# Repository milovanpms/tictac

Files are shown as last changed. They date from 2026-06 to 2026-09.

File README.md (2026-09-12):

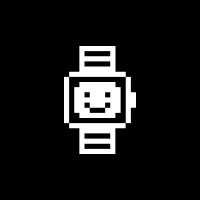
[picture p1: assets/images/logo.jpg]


**Tictac is a smartwatch prototype built on STM32G4, featuring heart rate monitoring, step counting and Bluetooth time sync on an e-ink display.**

Tictac is built around an e-ink display, a PPG heart rate sensor, a 6-axis accelerometer and a Bluetooth module, all packed into a custom-routed PCB and a fully 3D-printed enclosure. 

*The project spans embedded C on STM32G4, signal processing prototyped in MATLAB, PCB design in Altium Designer, mechanical design in Fusion 360, and a companion Android app; all developed from scratch over one semester.*

<p align="center">
  
  
  
  
  
  
</p>

<h1 align="center"></h1>

<h5 align="center"><a href="https://milovan.me">milovan.me</a></h5>

## In a nutshell
- **What** : A smartwatch prototype with heart rate monitoring, step counting, time display and Bluetooth sync.
- **Why** : We wanted a project that was both technically ambitious and tangible; something you can actually wear and demo.
- **Context** : Embedded systems student project, two-person team.

## Showcase

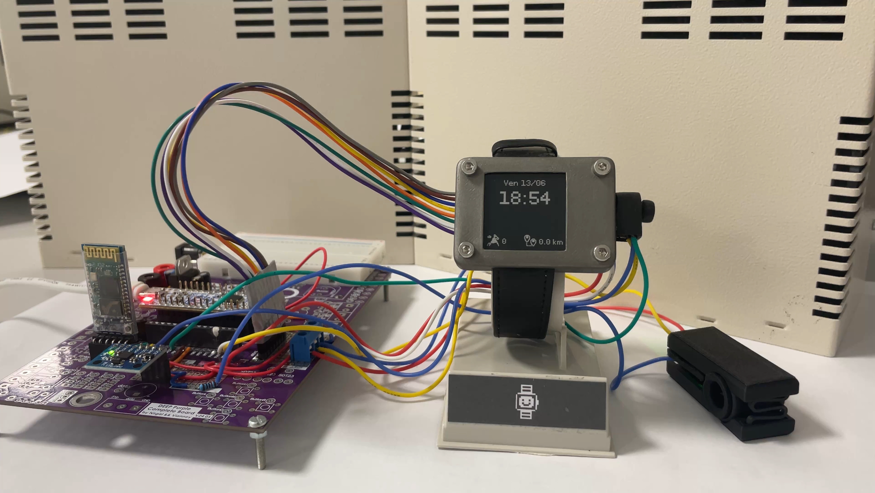
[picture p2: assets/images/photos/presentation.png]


## Documentation
### Find your happiness:
- ⚙️ [Hardware Architecture](./docs/architecture.md): Component list, pin mapping and wiring
- 🛠️ [Firmware](./docs/firmware.md): STM32G4, state machines, code architecture
- 📶 [Connectivity](./docs/connectivity.md): Bluetooth usage and handling
- 💓 [Heart-Rate Measurement](./docs/heartrate.md): PPG acquisition, bandpass filtering and BPM calculation
- 👟 [Step Counter](./docs/stepcounter.md): Accelerometer-based step detection and distance estimation
- 👤 [Human-Machine Interface](./docs/hmi.md): E-ink display, rotary encoder and menu navigation
- 🔌 ~~[Electronics](./docs/electronics.md): Altium schematic, PCB routing, JLCPCB validation~~
- 📐 [Mechanical Design](./docs/cad.md): 3D-printed enclosure, pulse sensor jaw, dial and screen housing

## Repository Structure
```
├── hardware/        # Altium schematics, PCB
├── firmware/        # Source code
├── matlab/          # Signal processing scripts (PPG, pedometer)
├── docs/            # Documentation, conception notes
├── assets/          # Images, schematics and illustrations
└── case/            # 3D models
```

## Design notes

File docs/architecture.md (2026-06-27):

# ⚙️ Hardware Architecture
 
## Overview
 
Tictac is built around an **STM32G431KB** (Cortex-M4F), which handles everything: the e-paper
display via SPI, the accelerometer via I2C, the pulse sensor via ADC, Bluetooth and debug
console via UART, and GPIO/EXTI for the buttons and rotary encoder.
 
### Why the G431KB?
 
This was the microcontroller imposed by the academic framework the project was built under
(a Nucleo-G431KB board), so "why this chip" wasn't really a choice we made
freely. It turned out to be a genuinely good fit: a single chip exposing SPI, I2C,
two independent UARTs and a 12-bit ADC covers every peripheral the watch needs; e-paper,
accelerometer, pulse sensor, Bluetooth. The Cortex-M4F core
also brings a hardware FPU, which is put to use in the floating-point band-pass filtering applied
to both the PPG and the accelerometer signals (see [Heart-rate documentation](./heartrate.md) and
[Step Counter documentation](./stepcounter.md)).

## Two hardware platforms
 
Like most projects, Tictac went through two distinct hardware stages:
 
- A **Nucleo-G431KB**, plugged into the school's generic prototyping baseboard, used to validate firmware and sensors before any custom PCB existed.
- A fully custom **2-layer PCB**, designed in Altium Designer around the bare
  **STM32G431KBTx**.

## Functional block diagram
 
> [!NOTE]
> Diagram to be added in a *very near* future...

## Component Details
 
| Block | Component | Role |
|---|---|---|
| Microcontroller | **STM32G431KB** (Cortex-M4F) | Main processing: GPIO, ADC, I2C, SPI, UART |
| Display | **epd1in54_V2** e-paper, `200×200 px` | Main UI: time, menus, measurement screens |
| Heart-rate sensor | **HW827** | Optical PPG sensor (~525 nm green LED), analog output |
| Motion sensor | **MPU6050** | 6-axis accelerometer/gyroscope, used for step counting |
| Connectivity | **HC-05** | Bluetooth-to-UART bridge to the companion Android app |
| User input | Rotary encoder (2-phase quadrature) | Menu navigation (rotate left / right) |
| User input | Push button ×1 (central) | Menu select / confirm |
 
> [!NOTE]
> What the firmware calls the "left" and "right" buttons (`BTN_GAUCHE`, `BTN_DROIT`) are **not**
> two separate pushbuttons. They are the two quadrature phases of a single rotary encoder. Only
> the **central** button is an actual independent pushbutton. See [HMI documentation](./hmi.md) for the
> decoding logic.

## Pin Mapping
 
| Component | Pin | STM32G431KB GPIO | Interface |
|---|---|---|---|
| **HW827** (pulse sensor) | analog out | `PA0` (`ADC1_IN1`) | ADC |
| Debug console | `TX` | `PA2` | UART2 |
| Debug console | `RX` | `PA3` | UART2 |
| **epd1in54_V2** | `CS` | `PA4` | SPI1 |
| **epd1in54_V2** | `SCK` | `PA5` | SPI1 |
| SPI1 MISO (unused by e-paper) | – | `PA6` | SPI1 |
| **epd1in54_V2** | `MOSI` | `PA7` | SPI1 |
| **epd1in54_V2** | `DC` | `PA8` | GPIO |
| **HC-05** (Bluetooth) | `TX` | `PA9` | UART1 |
| **HC-05** (Bluetooth) | `RX` | `PA10` | UART1 |
| Central button | – | `PA11` | GPIO (input, pull-down) |
| Rotary encoder | Phase A ("left") | `PA12` | GPIO / EXTI (pull-up) |
| **MPU6050** | `SCL` | `PA15` | I2C1 |
| **epd1in54_V2** | `BUSY` | `PB0` | GPIO (input) |
| **epd1in54_V2** | `RST` | `PB3` | GPIO (output) |
| Rotary encoder | Phase B ("right") | `PB5` | GPIO / EXTI (pull-up) |
| **MPU6050** | `SDA` | `PB7` | I2C1 |

> [!NOTE]
> The e-paper SPI bus has no MISO line. The `epd1in54_V2` only ever receives data (frame buffer
> and commands); it never talks back to the MCU over SPI. `BUSY` is the only signal flowing the
> other way, and it's a plain GPIO read, not part of the SPI peripheral itself.

## Software Peripheral Configuration
 
All of the above is mirrored at firmware level in `config.h`, which acts as a single switchboard
enabling or disabling every BSP module used in the project:
 
```c
#define USE_BSP_TIMER   1   // Timer 4, used for periodic step-detection polling
#define USE_BSP_EXTIT   1   // External interrupts, used for the rotary encoder
#define USE_RTC         1   // Real-time clock, used for the watch face
 
#define USE_ADC         1
#define USE_IN1         1   // PA0; HW827 pulse sensor
 
#define USE_EPAPER      1   // epd1in54_V2, drives USE_SPI automatically
#define USE_MPU6050     1   // Accelerometer/gyroscope, drives USE_I2C automatically
```
 
Two UARTs are configured independently for two completely different purposes:
 
- **UART1** (`PA9`/`PA10`) is dedicated to the **HC-05** Bluetooth module — see
  [Connectivity documentation](./connectivity.md).
- **UART2** (`PA2`/`PA3`) is the debug console (`115200` baud), redirected to `printf()` via
  `BSP_SYS_set_std_usart()` in `main.c`. Every `printf()` call in the firmware, such as state machine
  transitions, sensor init status and error messages, ends up here.

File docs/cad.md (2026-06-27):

# 🖨️ Mechanical Design

## Overview

All mechanical parts for Tictac were designed in **Autodesk Fusion** and printed on a FDM printer. Three independent assemblies were produced:

- **The heart-rate sensor jaw:** A spring-loaded clamp that holds the finger against the HW827 optical sensor.
* **The rotary encoder housing:** A two-part shell that retains the encoder and the central push-button, topped by a custom knob.
- **The screen enclosure:** A two-part case that houses the e-paper display and provides strap attachment points.

Every part was tolerance-tested on the actual printer before the final print run; the clearance test settled on **0.5 mm** of play for moving joints and press-fit inserts.

## Heart-Rate Sensor Jaw
 
The jaw is the most mechanically complex sub-assembly. Its job is to press the user's finger firmly and consistently against the HW827's photodiode window, at the right angle and with the right contact force, because PPG signal quality is very sensitive to both.

> [!NOTE]
> The HW827 outputs a raw analog voltage; there is no pressure feedback. The jaw design
> trades the complexity of active force control for a passive spring mechanism calibrated
> to a typical fingertip.

The assembly is made up of five distinct parts described below.

<p align="center">
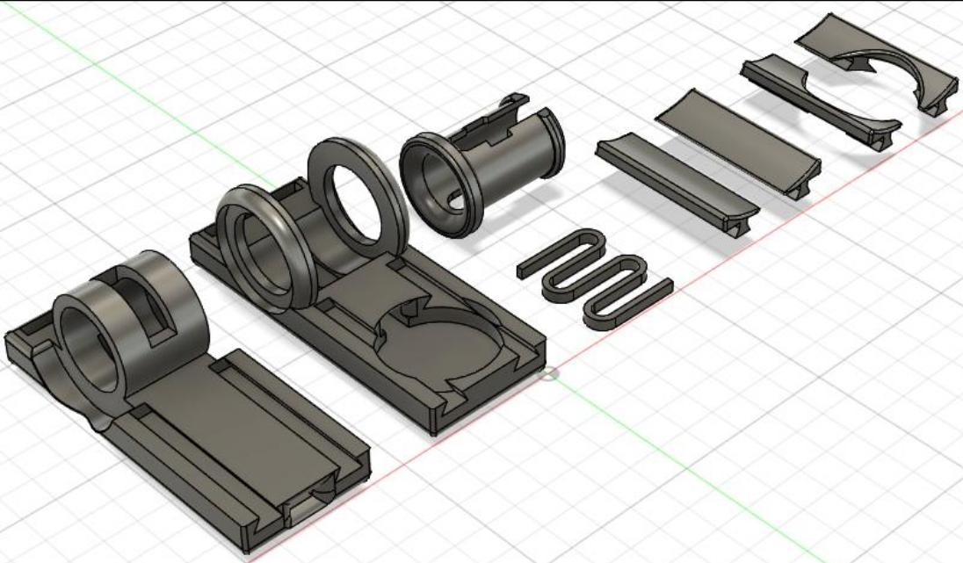
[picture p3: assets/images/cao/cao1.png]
  
</p> 

### Lower Jaw
 
<p align="center">
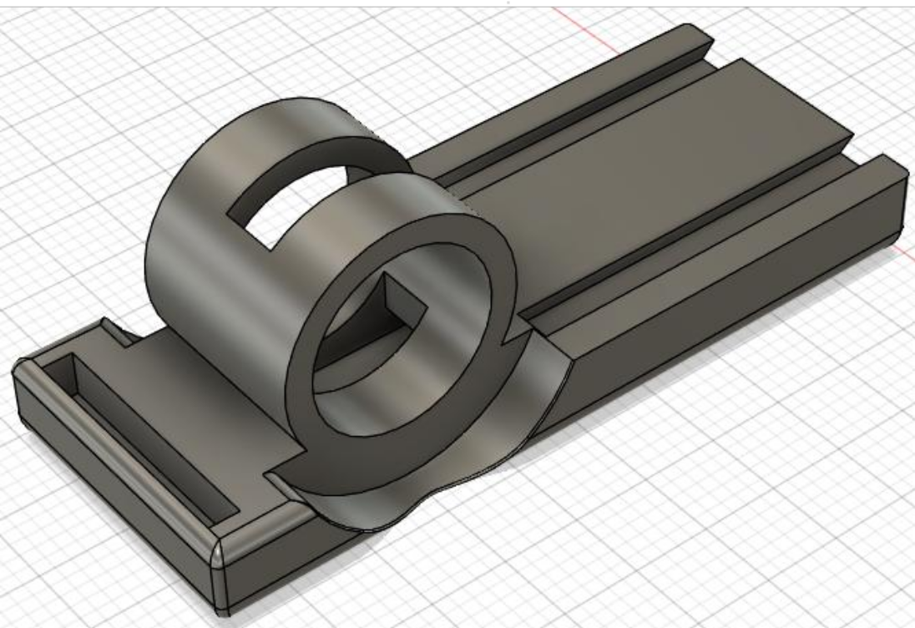
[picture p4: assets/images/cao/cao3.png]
  
</p> 
 
The lower jaw is the fixed base of the assembly. It is built around a rectangular main body that integrates several purpose-shaped inserts:

| Insert | Shape | Purpose |
|---|---|---|
| Spring seat | Rectangular | Locks the spring in place without adhesive |
| Pivot insert | Cylindrical, split | Receives the pivot axis and interlocks with the upper jaw |
| TPU pad seats | Trapezoidal | Friction-fit retention for the comfort pads |
| Sensor pocket | Flat-bottomed recess | Locates and protects the HW827 module |

A cable routing groove runs along the full length of the body and continues into the pivot zone, so the sensor wires reach the PCB without being pinched by the pivot motion. Two short cylindrical bosses on either side of the pivot zone mate with matching recesses in the upper jaw to form the hinge.

Chamfers and fillets are applied to all exposed edges for print quality and comfort.

### Upper Jaw

<p align="center">
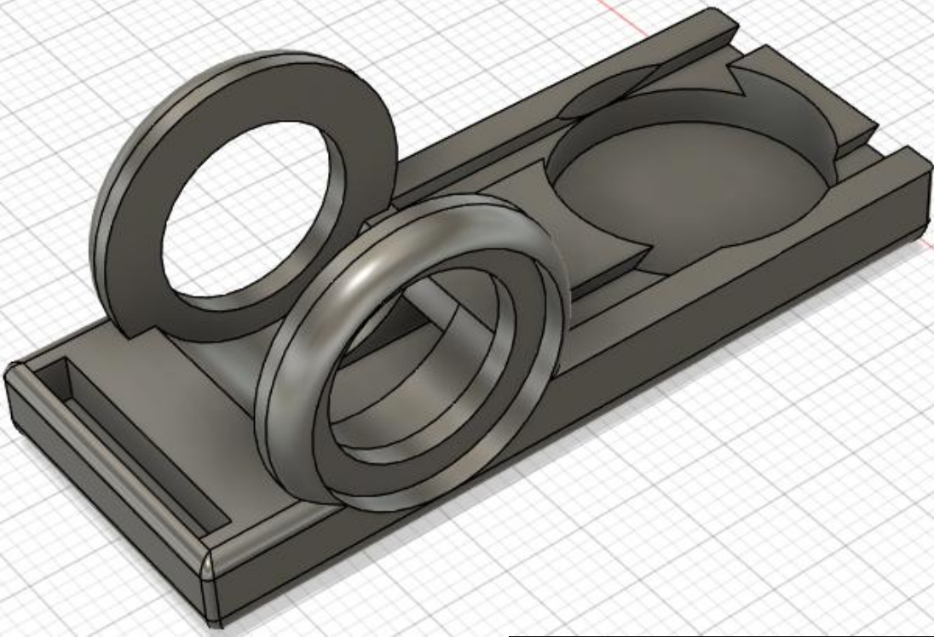
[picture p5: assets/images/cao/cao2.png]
  
</p> 

The upper jaw mirrors the lower jaw's base volume and carries the same set of inserts; spring seat, TPU pad seats, and two cylindrical sockets that receive the lower jaw's hinge bosses, plus a central cylindrical hub that wraps around the pivot axis.
 
A cable groove identical to the lower jaw's is present, extended all the way through the hub, so that wires can exit toward the watch body once the jaw is assembled and closed around a finger.

### Pivot Axis
 
<p align="center">
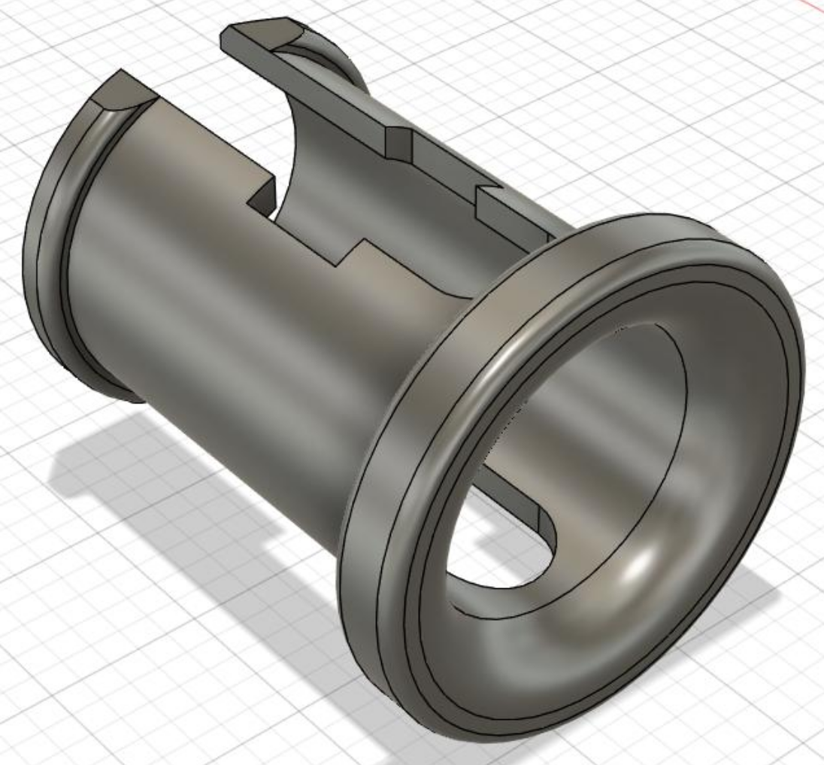
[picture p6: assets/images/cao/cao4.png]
  
</p> 
 
The pivot axis is a stepped cylinder designed with **0.5 mm** clearance (matching the printer's calibrated tolerance). Key design decisions:
 
* A lengthwise slit allows the cylinder to compress slightly during insertion without
  cracking, acting as a snap-fit.
- A through-channel for cable routing runs the full length of the axis, aligning with the
  grooves in both jaws when assembled.

### TPU Comfort Pads

<p align="center">
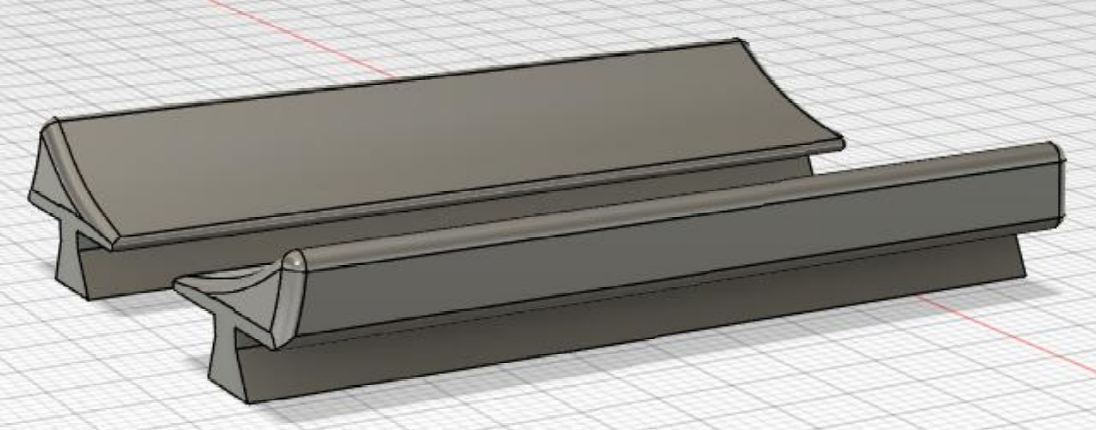
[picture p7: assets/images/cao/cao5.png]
  
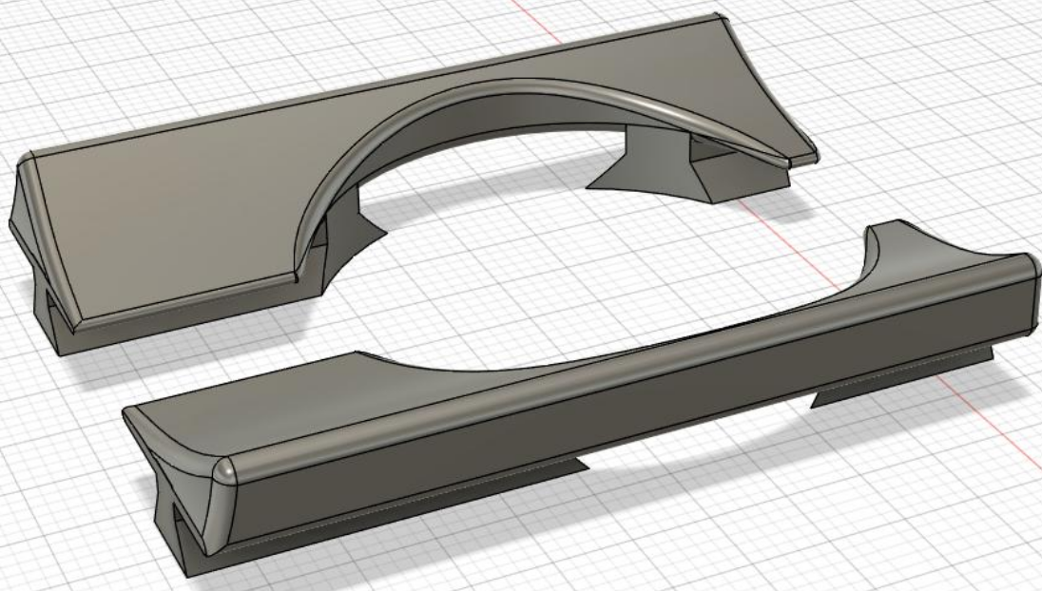
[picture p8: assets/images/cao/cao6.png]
  
</p> 
 
Four distinct TPU pads (two upper, two lower) press-fit into their trapezoidal seats with 0.5 mm of play. TPU was chosen because it is flexible enough to conform to the finger's shape and can be printed on the same printer as the rigid PLA parts, just with a different filament loaded. The trapezoidal cross-section prevents the pads from pulling out under the spring's closing force.
 
A clearance slot on the lower jaw's pad seats allows the HW827 sensor module to be swapped out independently, without having to disassemble the entire jaw.

### 3D-Printed Spring

<p align="center">
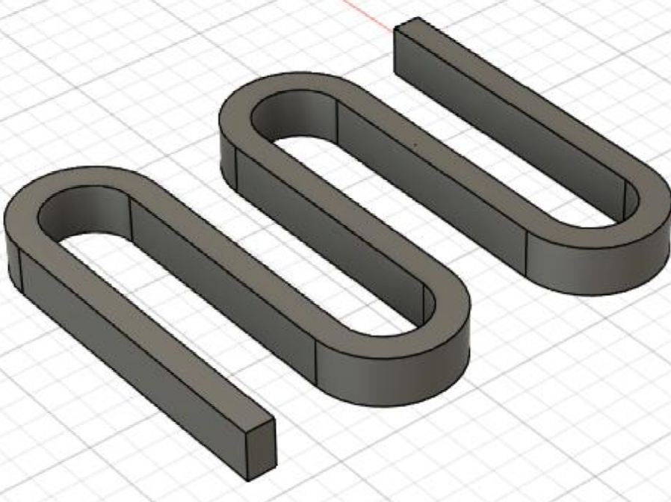
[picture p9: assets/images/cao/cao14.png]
  
</p> 
 
The spring is a thick serpentine structure (1 mm wall thickness) printed in PLA.
 
> [!NOTE]
> Print orientation is critical here: the spring **must** be printed flat (i.e. the
> serpentine loops lying in the XY build plane). Printing it upright stacks the layer
> boundaries perpendicular to the bending stress, which causes delamination
> failure. The flat orientation distributes stress along layer lines instead of across
> them.

## Rotary Encoder Housing
 
The encoder used for menu navigation is a salvaged mouse scroll-wheel encoder; a bare quadrature encoder with **no integrated push-button**. A separate tactile push-button is placed behind it in the same housing. The housing's job is therefore twofold: combine both components into a single compact unit, and mechanically couple the knob's downward press to the push-button that sits behind the encoder's shaft.
 
The result is a single user-facing control that both rotates and clicks, even though those two functions come from two completely independent components. See [Architecture documentation](./architecture.md#component-details) and [Firmware documentation](./firmware.md#rotary-encoder-integration) for how the firmware reads each one.

<p align="center">
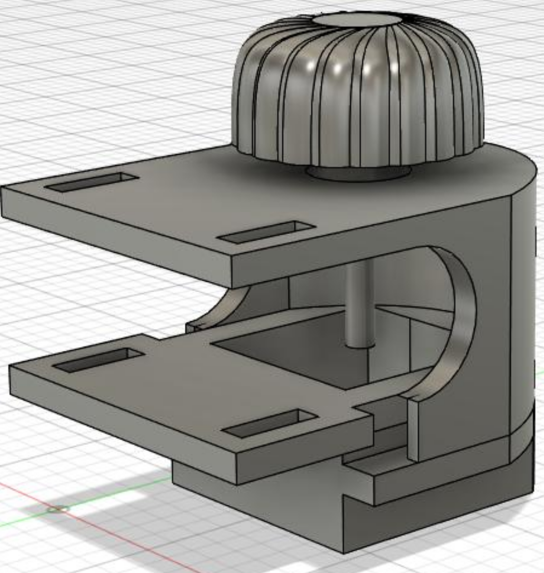
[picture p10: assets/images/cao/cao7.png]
  
</p> 

### Lower Shell
 
<p align="center">
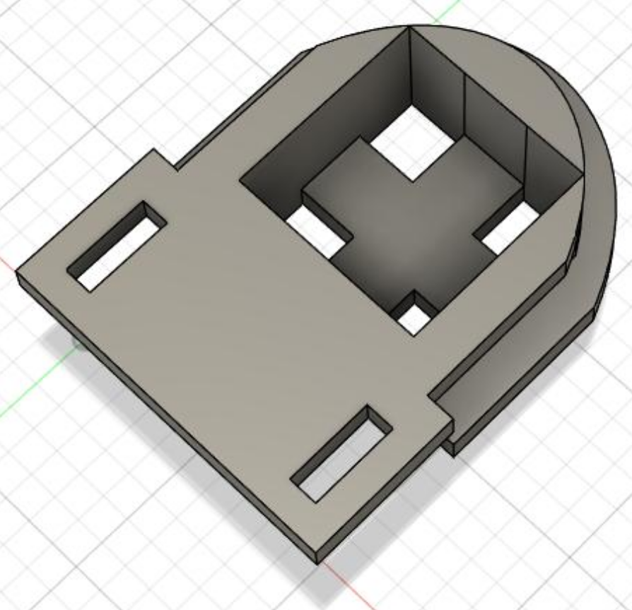
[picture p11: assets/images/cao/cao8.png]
  
</p> 
 
The lower shell holds both components in their correct relative positions. Two slots on opposite sides of the frame grip the mouse encoder's steel retaining tabs, fixing it horizontally and flush with the shell surface. Behind the encoder, a rectangular recess locates the push-button: four small pillars at the bottom of the recess align with the button's four legs for precise, repeatable placement.

### Upper Shell
 
<p align="center">
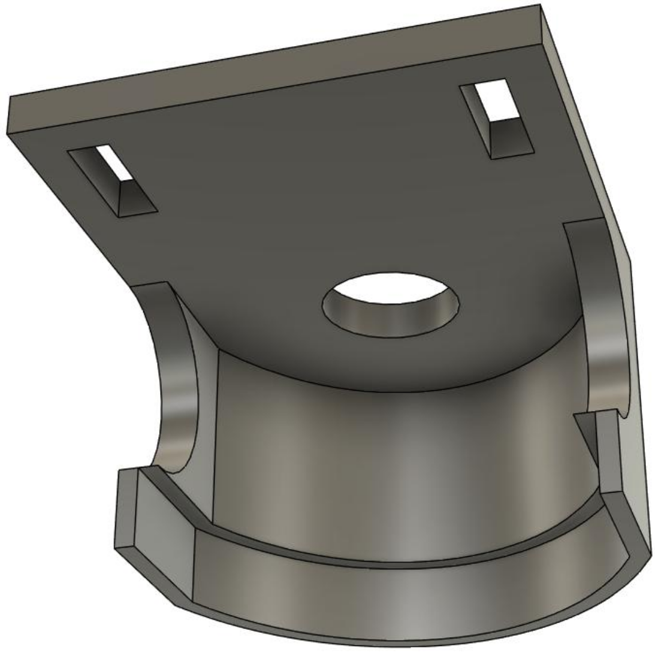
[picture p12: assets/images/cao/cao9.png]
  
</p> 
 
The upper shell constrains the encoder laterally but leaves it free to travel vertically. This vertical freedom is intentional: when the user presses the knob down, the encoder body slides inside the housing and its shaft end bears against the push-button behind it, actuating it. The shell depth is sized so the button can reach both its unpressed and fully-depressed positions without the encoder bottoming out on the shell walls.
 
A central cylindrical bore passes the encoder's shaft through to the outside.
 
### Knob
 
<p align="center">
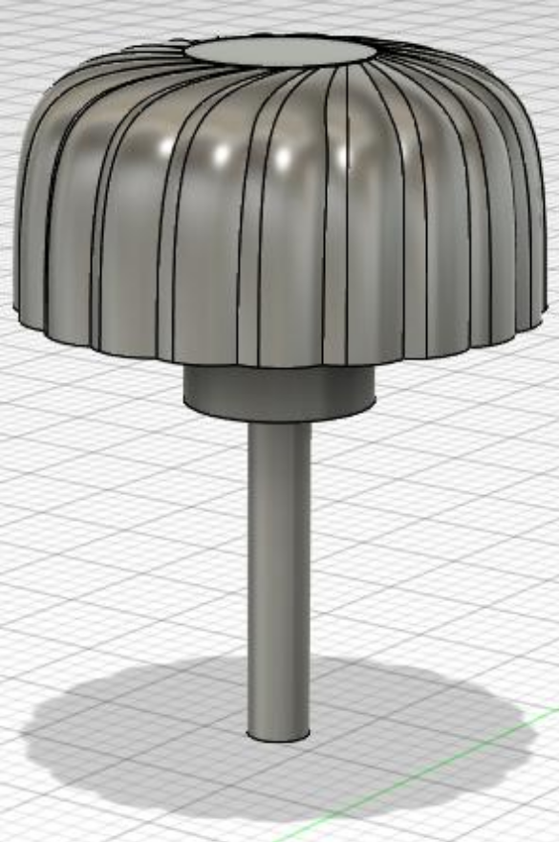
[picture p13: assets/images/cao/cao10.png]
  
</p> 
 
The knob is a three-part body in a single printed piece:
 
| Part | Role |
|---|---|
| Shaft insert | Press-fits onto the encoder's D-shaft to transmit rotation |
| Reinforcement base | Widens the cross-section just above the shaft insert to prevent cracking under torque |
| Outer grip dome | Finger-contact surface; a ring of symmetrically arranged rounded lobes provides grip |
 
The lobes are small enough that their surface finish was noticeably affected by printer
resolution. A light sanding pass after printing was needed to remove layer-step artefacts
before the knob felt smooth to use.

## Screen Enclosure
 
The screen enclosure houses the **epd1in54_V2** e-paper display (`200×200 px`, `1.54″`) and serves as the primary watch body that the user sees. See [Architecture documentation](./architecture.md#component-details) for display specs.
 
<p align="center">
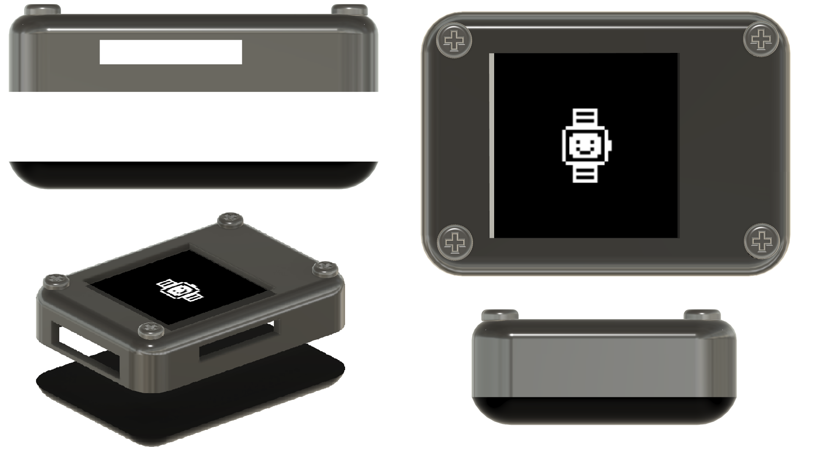
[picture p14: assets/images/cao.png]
  
</p> 
 
The enclosure is split into two parts along a horizontal parting line.

### Main Body

<p align="center">
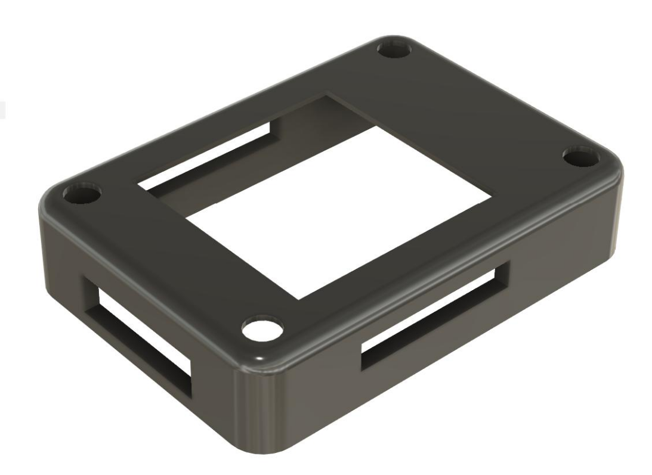
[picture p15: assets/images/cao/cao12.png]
  
</p>

The main body is a silver open frame designed around the display's footprint. It includes:
 
- A rectangular window exposing the active display area.
- Two lateral slots for attaching watch strap lugs.
- A cable passage channel for the SPI ribbon connecting to the PCB.
- A rectangular recess on one side that accepts the encoder housing as a snap-in
  sub-assembly.
All external edges carry fillets to soften the form. Four screw holes are present on the outer face, used to bolt the e-paper display module securely inside the enclosure.

### Cover

<p align="center">
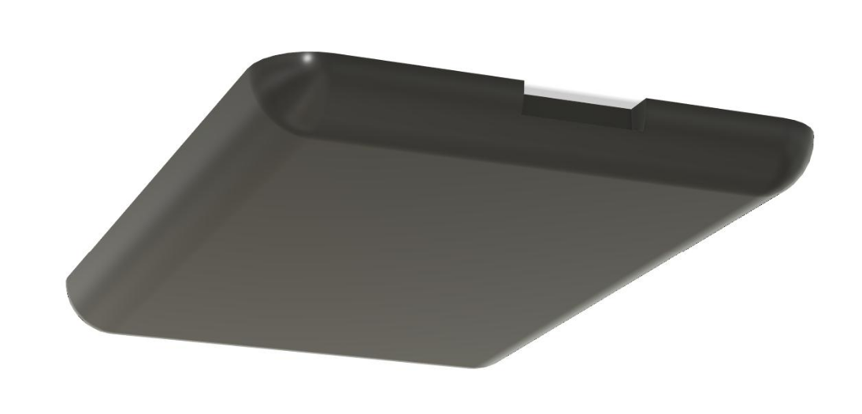
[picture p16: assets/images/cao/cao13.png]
  
</p>

The cover is a solid black parallelepiped with fully filleted edges. It has no clip, latch, or retention feature of any kind; a known design shortcoming. In practice it was held against the main body with poster tack. 

> [!NOTE]
> Yes, the back of a prototype smartwatch is held on with poster tack. No, this is not
> how consumer electronics are manufactured. For our defense, the deadline was approaching,
> but it held and the demo went fine!
 
## Print Settings Summary
 
| Parameter | Value |
|---|---|
| Material (structural parts) | PLA |
| Material (pads) | TPU |
| Clearance for moving joints | 0.5 mm |
| Clearance for press-fits | 0.5 mm |
| Spring print orientation | Flat (XY plane) |
| Post-processing | Sanding on knob grip surface |

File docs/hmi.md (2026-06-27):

# 👤 Human-Machine Interface
 
## Overview
 
The interface is deliberately minimal: one rotary encoder for navigation, one central pushbutton for validation, and a small monochrome display; here a `200×200px` Waveshare e-paper panel instead of an OLED. Low refresh rate and no touch input mean the UI leans entirely on the encoder + button + an icon grid rather than any kind of gesture or text input.
 
The low-level encoder/button driver details are covered in [Firmware documentation](./firmware.md#rotary-encoder-integration); this page covers what actually gets drawn, and how the menu's nested state machines fit together.

## Design tool
 
The screens themselves: icons, menu layouts, the measurement and result screens were designed in **Figma** before being translated into bitmaps and `Paint_DrawBitMap_Paste()` / `Paint_DrawString_EN()` calls in the firmware. Figma made it possible to lay out and iterate on the `200×200` monochrome interface visually before committing to pixel coordinates in C.

## Display Hardware
 
`EPD_SPI_Init()` configures **SPI1** as master for the e-paper:
 
```c
GPIO_InitStruct.Pin = GPIO_PIN_5 | GPIO_PIN_6 | GPIO_PIN_7; // PA5=SCK, PA6=MISO, PA7=MOSI
GPIO_InitStruct.Alternate = GPIO_AF5_SPI1;
...
hspi1.Init.BaudRatePrescaler = SPI_BAUDRATEPRESCALER_8;
```

`CS`, `DC`, `BUSY` and `RST` (see [Architecture documentation](./architecture.md#pin-mapping)) are plain GPIO, bit-banged from a lower driver layer; `EPD_SPI_Init()` only owns the three SPI1 bus pins.

### Init mode
 
| Function | Background | Used for | Called from `main.c`? |
|---|---|---|---|
| `EPD_Init()` | White (`0xFF`) | Full-screen redraw, called once at boot | **Yes** |
 
It allocates a `((200+7)/8) × 200 = 5000` byte, 1-bit-per-pixel buffer (`BlackImage`) via `malloc()`, then hand it to the `Paint_*` graphics library with a `90°` rotation.

## Idle Screen

<p align="center">
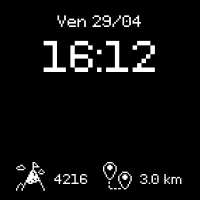
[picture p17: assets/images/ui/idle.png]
  
</p> 

```c
void EPD_Display_Idle(uint16_t pas) {
    Paint_DrawBitMap(image);
    /* ... time, date, step count and distance rendering, all commented out ... */
    EPD_1IN54_V2_Display(BlackImage);
}
```

## Main Menu
 
`EPD_DrawMenuFrames()` lays out four `71×71` boxes in a 2×2 grid (`16 px` gap), each holding a
`36×36` icon:

<p align="center">
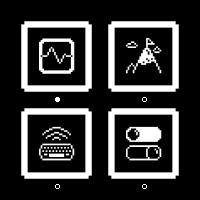
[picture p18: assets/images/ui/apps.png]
  
</p>

A filled/empty dot under each box (`EPD_UpdateMenuDisplay()`) shows the current selection (`etatActuel`, `1`–`4`), driven by the encoder (`EPD_MenuEncoderCallback()`, wraps circularly, `100 ms` debounce) and validated by the central button (`EPD_HandleMenuNavigation()`, polled every `10 ms`, on top of the button's own `50 ms` debounce; see [Firmware documentation](./firmware.md#central-button)). A `7 s` inactivity timeout (`IDLE_TIMEOUT_MS`) returns to the main menu, matching the user manual.
 
### NFC and Settings are stubs
 
Selecting `NFC` shows a static, non-interactive 3-icon screen (`EPD_Display_MenuNFC()`) with no button handling of its own. Selecting `PARAMETRES` does even less; its entire state-machine case is `currentState = MAIN; EPD_Display_Reset(); return SM_RUNNING;`: no settings screen is ever drawn, the menu just bounces straight back.

## Heart-Rate Submenu & Measurement: three nested state machines
 
The heart-rate feature is implemented as three state machines, each delegating to the next:
 
```
main.c: stateMachine()
  └─ MENU ──► EPD_StateMachine()                         [epaper_displays.c]
        └─ POULS ──► EPD_Pouls_StateMachine()            [epaper_pouls.c]
              └─ MESURE ──► EPD_Pouls_Mesure_StateMachine() [epaper_pouls_mesure.c]
                    ├─ MESURE: blocking HW827 recording + calcule_bpm() (~10.36 s)
                    └─ DONE:   show result for 5 s
```
 
Each layer has its own `MENU`/`DONE`-style states whose only job is to notice that the layer below just returned `SM_FINISHED`, and pass that fact up one level; on the next polling iteration, not the same one. Concretely: when the innermost measurement finishes, it takes **two extra passes through the outer state machines** before control is back at the idle screen; one for `EPD_Pouls_StateMachine()`'s own `DONE` state to fire, one more for `EPD_StateMachine()`'s.

### Pulse submenu
 
`EPD_Pouls_DrawMenuFrames()` draws two boxes side by side, reusing `statIcon` and `hommeCoeur` again; but here, the text label drawn underneath (`"Mesurer"` / `"Historique"`, toggled by drawing the inactive one in black-on-black to erase it without a full refresh) is what actually communicates the option, and it does match the resulting action:
 
```c
// EPD_Pouls_HandleMenuNavigation(), in epaper_pouls.c
case 1: currentState = MESURE;     break; // label shown: "Mesurer"
case 2: currentState = HISTORIQUE; break; // label shown: "Historique"
```

<p align="center">
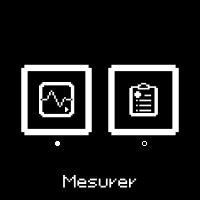
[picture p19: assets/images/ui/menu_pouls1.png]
  
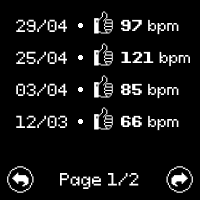
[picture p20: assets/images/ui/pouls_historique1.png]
  
</p>

`HISTORIQUE` itself is a stub: `currentState = DONE; EPD_Display_Reset(); return SM_RUNNING;`; no actual measurement history screen, just an immediate bounce back out.

### Measurement flow
 
1. `EPD_Display_MesureEnCours()`: A loading screen ("Mesure en cours / Ne bougez pas pendant la mesure").
2. In the same function call: `HW827_Recording_Process_1ms()`, `HW827_Recording_PrintCSV()`, then `calcule_bpm()`; the full ~10.36 s blocking pipeline documented in [Heart-Rate Measurement documentation](./heartrate.md).
3. `EPD_Display_MesureTerminee(bpm_moy)`: Shows the BPM value plus a 3-zone colour-coded health indicator: `< 120` (safe), `< 160` (caution), `> 160` (high), held for exactly `5000 ms` (non-blocking, `HAL_GetTick()`-based; unlike the measurement step itself).

<p align="center">
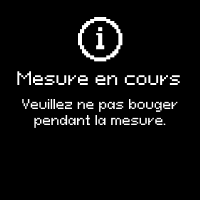
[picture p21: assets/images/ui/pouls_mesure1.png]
  
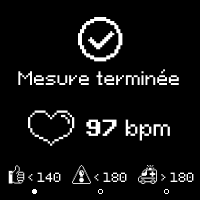
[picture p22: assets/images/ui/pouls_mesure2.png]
  
</p>

## Known Limitations
 
**The idle screen shows no live data** (time, date, steps, distance).

**`NFC`, `PARAMETRES`, the pulse submenu's `HISTORIQUE`, and the step history's day navigation**
are all non-functional placeholders.

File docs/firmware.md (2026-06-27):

# 🛠️ Firmware
 
## Overview
 
Tictac runs **bare-metal**: there's no RTOS, no tasks, no scheduler. `main()` boils down to a single infinite loop calling one function over and over:

```c
int main(void) {
    while (1) {
        stateMachine();
    }
}
```

Concurrency comes entirely from hardware interrupts layered on top of that loop: the rotary encoder reacts to GPIO/EXTI events, and the step counter reacts to a periodic hardware timer (see [Step Counter documentation](./stepcounter.md)), while everything else (buttons, Bluetooth, the clock) is handled by polling inside the loop itself.

## Main State Machine
 
`stateMachine()` in `main.c` implements a 4-state machine:
 
> [!NOTE]
> The block diagram is coming soon...

| State | Entered when | Does | Leads to |
|---|---|---|---|
| **`INIT`** | Once, at boot | Initialises every peripheral and driver (see below) | `IDLE` |
| **`IDLE`** | Right after `INIT`, or when leaving `MENU` | Resets and redraws the idle screen, snapshots the current time/date | `DETECTION` (immediately) |
| **`DETECTION`**| Right after `IDLE` | Polls Bluetooth (`handle_uart_reception()`), refreshes the clock if it changed, polls the central button | `MENU` on button press, otherwise stays |
| **`MENU`** | Central button press detected in `DETECTION` | Delegates entirely to `EPD_StateMachine()` (see [HMI documentation](./hmi.md)) | `IDLE` once `EPD_StateMachine()` returns `1` |

An unrecognised `currentState` value falls into a `default` case that resets straight back to `INIT`, meaning a corrupted state variable would silently replay the entire initialisation sequence rather than crash, harmless given that most of the init calls are idempotent register writes.

## Initialisation Sequence
 
Everything happens inside the `INIT` case, in this order:
 
1. **`HAL_Init()`**: STM32 HAL startup.
2. **`BSP_GPIO_enable()`**: Enables the GPIO clocks.
3. **UART2** (`115200` baud): Initialised and wired to `printf()` via `BSP_SYS_set_std_usart()`. Every debug message in the firmware goes through here (see [Architecture documentation](./architecture.md#software-peripheral-configuration)).
4. **UART1** (`115200` baud): The HC-05 Bluetooth link (see [Connectivity documentation](./connectivity.md)).
5. **ADC** (`BSP_ADC_init()`): Shared between the HW827 pulse sensor's channel and any other enabled analog input.
6. **RTC** (`RTC_Init()`): See below.
7. **MPU6050** (`MPU6050_Init()`): Accelerometer/gyroscope, `±8 g` / `±2000 °/s` (see [Step Counter documentation](./stepcounter.md)). A failed init here halts the firmware in an infinite `while(1);`. There's no fallback or retry, the watch simply locks up.
8. **`TIMER4`** (`BSP_TIMER_run_us(TIMER4_ID, 30000, true)`): Periodic interrupt feeding the step counter (see [Step Counter documentation](./stepcounter.md)).
9. **Encoder + central button GPIOs**: `PA12`/`PB5` configured with `EXTI` (rising+falling, pull-up); `PA11` (central button) configured as a polled input (pull-down).
10. **EXTI callbacks**: `encoder_callback` registered for both pin `12` and pin `5` via `BSP_EXTIT_set_callback()`.
11. **`lastEncoded = readEncoder();`**: See the note below.
12. **HW827** (`HW827_Init()`): Pulse sensor ADC setup (see [Heart-Rate documentation](./heartrate.md)).
13. **E-paper**: `EPD_SPI_Init()`, `DEV_Module_Init()`, `EPD_Init()`, then `EPD_DisplayBaseImage()` to draw the very first frame.

## Concurrency model: interrupts vs. polling
 
| Mechanism | Source | Handles |
|---|---|---|
| EXTI (`PA12`, `PB5`) | Rotary encoder phases | Direction detection ➜ `EPD_MenuEncoderCallback()` |
| Hardware timer (`TIMER4`, `30 ms`)| Periodic, configured in `main.c` | Step detection: 3-axis magnitude threshold (see [Step Counter documentation](./stepcounter.md)) |
| Polling, every `DETECTION` iteration | `handle_uart_reception()` | Bluetooth message reception (see [Connectivity documentation](./connectivity.md)) |
| Polling, every `DETECTION` iteration | `check_and_update_time_display()` | Idle-screen clock refresh |
| Polling, every `DETECTION` iteration | `read_central_button()` | Menu entry |

## Rotary Encoder Integration
 
The encoder's two quadrature phases are wired to `PA12`/`PB5` (see [Architecture documentation](./architecture.md#pin-mapping)), and direction detection happens entirely inside `encoder_callback()`, fired by EXTI on either pin:
 
1. A `5 ms` software debounce (`HAL_GetTick()`-based) rejects interrupts firing too close together.
2. The two pin states are combined into a 2-bit "Gray code" state (`pinA << 1 | pinB`).
3. A `switch` on the *previous* state determines whether the *new* state represents a clockwise or counter-clockwise step.
4. On a confirmed direction, `EPD_MenuEncoderCallback()` is called: direction `1` calls it with `-1`, and direction `-1` calls it with `+1`.

```c
if (direction == 1) {
    encoderPos++;
    EPD_MenuEncoderCallback(-1);
} else if (direction == -1) {
    encoderPos--;
    EPD_MenuEncoderCallback(1);
}
```

## Central Button
 
`read_central_button()` is polled once per `DETECTION` loop iteration. It debounces in software by timestamping the last valid press and requiring `50 ms` (`DEBOUNCE_TIME`) to pass before accepting a new one, and only fires on the rising edge. A single physical press returns `true` exactly once, regardless of how long the button stays held.

## Real-Time Clock
 
`RTC_Init()` does three things: initialise the RTC peripheral, **write** a hardcoded default time/date (`00:00:00`, Saturday, January 1st) to it, then immediately read it back into the same `time`/`date` globals declared in `rtc.h`.

```c
RTC_TimeTypeDef time = {0, 00, 00};
RTC_DateTypeDef date = {SATURDAY, JANUARY, 1, 00};
```

`RTC_GetDate()` / `RTC_GetHeure()` simply re-read the RTC and format it into static buffers (`"Lun 15/05"`, `"14:30"`) for the idle screen (see [HMI documentation](./hmi.md)).
 
These exact same `time` / `date` globals are also the ones written to by the Bluetooth `'z'` command (see [Connectivity documentation](./connectivity.md#supported-commands)): a phone-side time sync and the watch face's clock are reading and writing the same two structs.

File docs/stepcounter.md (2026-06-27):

# 👟 Step Counter
 
## Overview
 
The step count shown on the watch face comes from a hardware timer interrupt (`TIMER4`) paired with a threshold detector running on the **MPU6050**'s accelerometer data. This page documents that pipeline: how it's wired up in `main.c`, what it reads, and what its detection thresholds are.
 
## Hardware
 
The **MPU6050** is a 6-axis accelerometer + gyroscope, talking I2C1 on `PA15` (`SCL`) / `PB7` (`SDA`). See [Architecture documentation](./architecture.md#pin-mapping). `main.c` initialises it with:
 
```c
MPU6050_Init(&MPU6050_Data, GPIOA, GPIO_PIN_0, MPU6050_Device_0,
             MPU6050_Accelerometer_8G, MPU6050_Gyroscope_2000s);
```
 
- **`MPU6050_Device_0`**: The sensor's `AD0` pin is wired low, putting it at I2C address `0xD0`.
- **`MPU6050_Accelerometer_8G`** / **`MPU6050_Gyroscope_2000s`**: The widest available ranges on both axes; sensible for a wrist-worn device that can see fairly sharp accelerations.

## Live path: timer interrupt + threshold detection
 
This is the step counter that actually runs on the watch. `main.c` arms a periodic hardware timer during initialisation:
 
```c
BSP_TIMER_run_us(TIMER4_ID, 30000, true); // fires every 30 ms
```

Each time it fires, the interrupt handler (`TIMER4_user_handler_it`, in `stm32g4_timer.c`) does the following:
 
1. Calls `MPU6050_ReadAll()` to refresh `MPU6050_Data`.
2. Combines all three axes into a single magnitude: `abs(X) + abs(Y) + abs(Z)`; a sum of absolute values.
3. Compares that magnitude against a threshold (`SEUIL`).
4. If it's above threshold, **and** a debounce flag (`dans_pic`) confirms this isn't the same peak as last time, **and** at least `TEMPS_MORT` has passed since the last accepted step (`HAL_GetTick()`-based), increments the global `pas_interupt` counter and sets `dans_pic = true`.
5. Once the magnitude drops back under the threshold, `dans_pic` is reset to `false`, arming the detector for the next step.

```c
int32_t magnitude = abs(MPU6050_Data.Accelerometer_X)
                   + abs(MPU6050_Data.Accelerometer_Y)
                   + abs(MPU6050_Data.Accelerometer_Z);
 
if (magnitude > SEUIL) {
    if (!dans_pic && (maintenant - dernier_pas_timestamp > TEMPS_MORT)) {
        pas_interupt++;
        dans_pic = true;
        dernier_pas_timestamp = maintenant;
    }
} else {
    dans_pic = false;
}
```
 
`SEUIL` and `TEMPS_MORT` are defined in `stm32g4_timer.h`:
 
```c
#define SEUIL       4500
#define TEMPS_MORT  200
```

```c
volatile uint16_t pas_interupt = 0; // declared in main.c
```
 
`pas_interupt` is then read directly by the display layer every time the idle screen refreshes:
 
```c
EPD_Display_Idle(pas_interupt); // in check_and_update_time_display() and the IDLE state
```

| Parameter | Value |
|---|---|
| Timer period | `30 ms` |
| Threshold (`SEUIL`) | `4500` |
| Debounce (`TEMPS_MORT`) | `200 ms`|
| Axes used | All 3: `abs(X) + abs(Y) + abs(Z)`|

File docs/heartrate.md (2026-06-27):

# 💓 Heart-Rate Measurement
 
## A pulse's journey through the system
 
```
HW827 (analog PPG) ➜ ADC1_IN1 @ ~71.43 Hz, 1 sample / 14 ms ➜ Raw buffer (740 samples, ~10.36 s) ➜ Float conversion ➜ Band-pass filter (moving-average low-pass + subtraction high-pass) ➜ Adaptive threshold (0.1 × std) ➜ Peak detection (≥ 0.4 s apart) ➜ BPM averaging
```
 
The whole pipeline lives in `heartbeat.c`, and unlike the accelerometer pipeline (see [Step Counter documentation](./stepcounter.md)), it runs as a single **blocking** sequence rather than a background interrupt: the user presses the heart-rate menu entry, the watch freezes on a loading screen for about ten seconds while it samples and crunches the signal, then shows a BPM value.

## Hardware: the HW827 sensor
 
> ### What is photoplethysmography (PPG)?
> PPG is an optical method for measuring blood volume changes at the skin's surface. A green LED
> (~525 nm) shines into the skin, and a photodiode measures how much of that light gets reflected
> back. Blood absorbs green light more than surrounding tissue does, so each heartbeat, which
> pushes a small pulse of blood through the capillaries, shows up as a tiny dip in the reflected
> light, repeating at the heart rate.

The **HW827** outputs this measurement as a single analog voltage, read directly by the **STM32G431KB**'s internal ADC on `PA0` (`ADC1_IN1`, see [Architecture documentation](./architecture.md#pin-mapping)). A sensor like this is a convenient match for a single-MCU design: no I2C/SPI driver, no register configuration, just one ADC channel to sample.

## Acquisition
 
### Sampling parameters
 
| Parameter | Value |
|---|---|
| Sample interval | `14 ms` (`HW827_SAMPLE_TIME`)  |
| Sampling rate (`FS`)  | `1000 / 14 ≈ 71.43 Hz` |
| Samples per recording | `740` (`HW827_RECORDING_SIZE`) |
| Recording duration | `740 × 14 ms ≈ 10.36 s` |
| ADC channel | `ADC1`, `ADC1_IN1` (`PA0`) |
| Acquisition mode | Blocking, one `HAL_Delay()` per sample |

### `HW827_Recording_Process_1ms()`
 
Despite its name (a holdover from an originally interrupt-driven, millisecond-tick design), this function is fully blocking: it loops `740` times, reading one ADC sample and sleeping `14 ms` on every iteration, for a total of ~10.36 seconds with the CPU unavailable for anything else.

```c
while (hw827_index < HW827_RECORDING_SIZE) {
    hw827_data[hw827_index++] = BSP_ADC_getValue(ADC_1);
    printf("#");                  // progress indicator
    HAL_Delay(HW827_SAMPLE_TIME); // 14 ms
}
```

When `HW827_TEST_MODE` is enabled (it is, by default; see `heartbeat.h`), the `#` characters printed on every sample give a simple `[#####...#####]` progress bar on the debug console for the full duration of the recording.

### CSV export: `HW827_Recording_PrintCSV()`
 
The raw buffer can be dumped over the debug UART as a MATLAB compatible array (`bat = [...]`). This is exactly the format consumed by the project's MATLAB validation script (see below). Recorded data can be pasted straight from the serial console into MATLAB without any reformatting.

## From MATLAB prototype to embedded C
 
Before being ported to C, the filtering and peak-detection logic was first developed and validated in MATLAB on real recorded PPG traces. That prototype used a proper 3rd-order **Butterworth** band-pass filter (`0.5–5 Hz`, applied bidirectionally with `filtfilt` to avoid phase distortion), an adaptive threshold of `mean + 0.5 × std`, and a `0.4 s` minimum peak distance. On one recorded sample, it measured a mean heart rate of `103.0 bpm` (min `42.9`, max `112.8`).
 
The embedded version keeps the same overall shape: filter, adaptive threshold, peak detection, BPM from inter-peak intervals, but trades the Butterworth IIR filter for something much cheaper to run on a microcontroller without a DSP/filter library: a moving-average low-pass followed by subtraction. See [Step Counter documentation](./stepcounter.md) for the equivalent trade-off made on the accelerometer side.

## Signal Pre-Processing
 
### Band-pass filter: `bandpass_filter_ppg()`
 
The filter runs in two conceptual steps, both folded into a single pass over the data:
 
1. **Low-pass**: A 5-point moving average, giving a cutoff around `FS / 5 ≈ 14.28 Hz`.
2. **High-pass**: The moving average is subtracted from the original signal, removing the slow
   baseline drift (motion, ambient light changes) while keeping faster pulsatile variations.

### Adaptive threshold
 
Before peak detection, `calcule_bpm()` computes the mean and standard deviation of the filtered
signal, then derives a threshold from it:
 
| Mode | Threshold formula |
|---|---|
| Normal (`HW827_BYPASS_FILTER = 0`) | `0.1 × std(filtered)` |
| Bypass (`HW827_BYPASS_FILTER = 1`) | `max(0.1 × std(raw), 50.0)` |
 
The bypass mode skips `bandpass_filter_ppg()` entirely and runs peak detection directly on the raw ADC samples, with a hard floor of `50` on the threshold to compensate for not having removed the DC bias. It exists as a debug/comparison switch, toggled by hand in `heartbeat.h` rather than at runtime.

## Peak Detection: `find_peaks()`
 
A sample is counted as a heartbeat if it satisfies three conditions:
 
1. It's above the adaptive `threshold`.
2. It's a local maximum (`signal[i] > signal[i-1]` and `signal[i] > signal[i+1]`).
3. It's at least `min_dist` samples away from the previously accepted peak.

| Parameter | Value |
|---|---|
| `MIN_PEAK_DIST_SEC` | `0.4 s` |
| `MIN_PEAK_DIST_SAMPLES`| `(uint16_t)(FS × 0.4) ≈ 28 samples`  |
 
That `0.4 s` minimum spacing between two accepted beats also sets an implicit ceiling on what the algorithm can ever report: `60 / 0.4 = 150 bpm` maximum, regardless of what the sensor sees.

## BPM Calculation: `calcule_bpm()`
 
Once peaks are found, the BPM is the average of the instantaneous rate across every consecutive pair of detected peaks:
 
```c
float dt = (peak_locs[i] - peak_locs[i - 1]) * HW827_SAMPLE_PERIODE; // seconds
float bpm_inst = 60.0f / dt;
```

`*bpm_moy` is the mean of all `bpm_inst` values, and is reported as `0` if fewer than 2 peaks were found (one peak alone gives no interval to measure).
 
`calcule_bpm()` also prints a detailed trace to the debug console on every run: a handful of filtered sample values, the computed mean/std/threshold, how many samples exceeded the threshold, every detected peak-to-peak interval with its instantaneous BPM, and the final result.

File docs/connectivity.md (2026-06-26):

# 📶 Connectivity
 
## Why Bluetooth, and why HC-05
 
The watch has no internet connectivity of its own. Any exchange with the outside world (in practice, just time synchronisation) has to go through a paired smartphone or tablet running a dedicated companion app. Bluetooth is the obvious fit here: it's the one wireless link that's both standard on every phone and easy to bridge into a microcontroller's UART.
 
That's exactly what the **HC-05** module is. It's a classic Bluetooth module: from the phone's side it shows up as a normal Bluetooth device, and from the **STM32G431KB**'s side it's nothing more than a UART peripheral. There's no Bluetooth stack to implement on the MCU: the HC-05 handles all of that on its own firmware, and simply forwards whatever bytes it receives over the air onto its TX/RX pins.
 
See [Architecture documentation](./architecture.md#pin-mapping) for the physical pin mapping (`PA9`/`PA10`).

## Protocol overview
 
UART over Bluetooth is already a reliable, ordered, point-to-point byte stream. The protocol is intentionally minimal: plain ASCII text commands, one per line.

### Frame format
 
| Field | Size | Description |
|---|---|---|
| Command char | `1 byte`  | Selects the action to perform (currently: `z`) |
| Parameters | variable  | ASCII fields specific to the command, separated by `:` and `/` |
| Terminator | `1 byte`  | `\n` or `\r` marks the end of the message |

### Supported commands
 
| Command | Format | Effect |
|---|---|---|
| `z` | `zHH:MM:SS;DD/MM/YYYY` | Parses the date and time, writes them to the RTC |

```c
// process_received_message(), case 'z':
sscanf(receive_buffer + 1, "%d:%d:%d;%d/%d/%d",
       &hours, &minutes, &seconds, &day, &month, &year);
```

> [!NOTE]
> Only one command exists today, but the `switch` on `receive_buffer[0]` is built to scale: a future phone-side feature (pulling step history, configuring an alarm, etc.) just needs one more `case`, not a redesign of the protocol.

## Reception pipeline
 
```
HC-05 (UART1 RX) ➜ handle_uart_reception() ➜ receive_buffer[64] ➜ process_received_message() ➜ RTC
```
 
`handle_uart_reception()` is **polled**, not interrupt-driven: it's called on every iteration of the `DETECTION` state in `main.c`'s main loop (see [Firmware documentation](./firmware.md)), and simply does nothing if no byte is waiting:
 
```c
while (BSP_UART_data_ready(UART1_ID)) {
    received_char = BSP_UART_getc(UART1_ID);
    BSP_UART_putc(UART2_ID, received_char);   // echoed to the debug console
    ...
}
```

Every received character is echoed onto **UART2** (the debug console, see [Architecture documentation](./architecture.md#software-peripheral-configuration)) as it comes in. This makes raw Bluetooth traffic visible live in a serial terminal; practical for debugging the phone app, at the cost of a noisier debug console.

Characters accumulate in `receive_buffer` until a `\n` or `\r` is seen, at which point the buffer is null-terminated and handed off to `process_received_message()`.

### Buffer management
 
`receive_buffer` is a fixed `64`-byte array. The write is bounds-checked (`buffer_index < BUFFER_SIZE - 1`), so there's no risk of overflowing memory. However, a message longer than 63 characters before its terminator will simply have its extra bytes dropped rather than rejected outright, since the function keeps consuming characters from UART1 either way.

## Time synchronisation with the companion app
 
After pairing the phone with the device named **"Tictac"** in the system Bluetooth settings, the companion app exposes a sync button. Pressing it sends a `z` command with the phone's current date and time, which the firmware applies to the RTC via `BSP_RTC_set_time()` / `BSP_RTC_set_date()`. From that point on the watch keeps time on its own, entirely independent of the phone; sync is a one-shot push, not a maintained connection, and can be repeated at any time by pressing the button again.

## Known Limitations
 
**One-way only.** Data only ever flows from the phone to the watch (time sync). There is no command to pull step count, distance or heart-rate history back out over Bluetooth.
 
**No acknowledgement.** The app has no way of knowing whether a `z` command actually succeeded: if `sscanf()` fails to match all six fields, `process_received_message()` does nothing, and no error is reported back over UART1.
 
**NFC was the planned second channel, never implemented.** The original specifications included NFC (via a PN532 module) for badge emulation/duplication. It never made it into the firmware. Bluetooth, documented here, is the device's only working connectivity today.

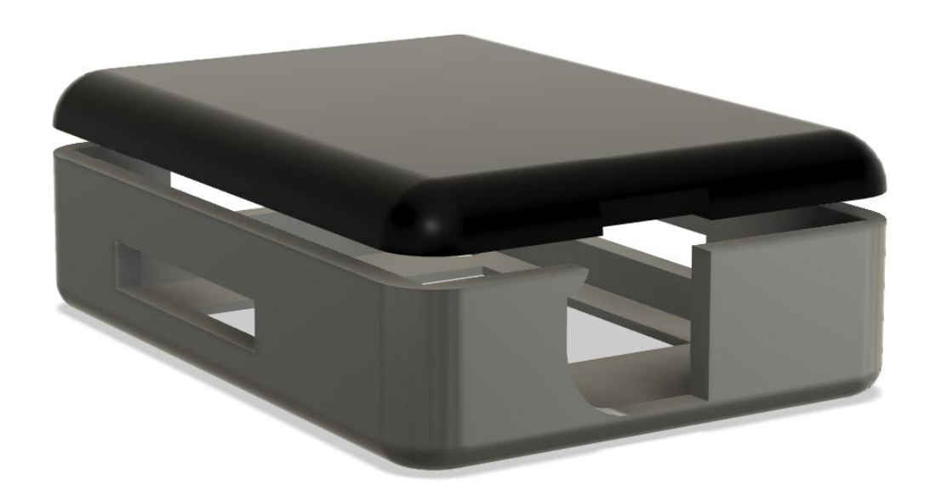
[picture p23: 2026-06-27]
assets/images/cao/cao11.png

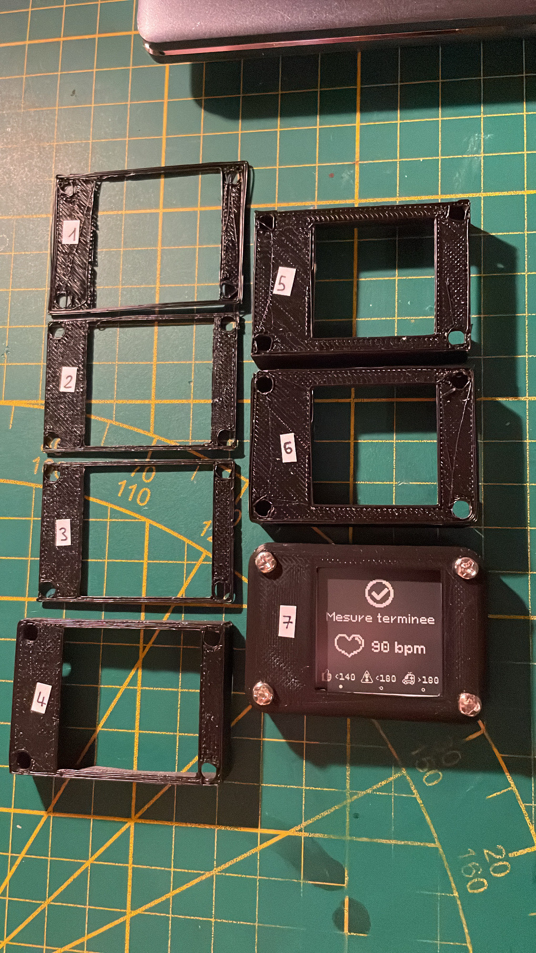
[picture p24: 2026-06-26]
assets/images/photos/A.jpg

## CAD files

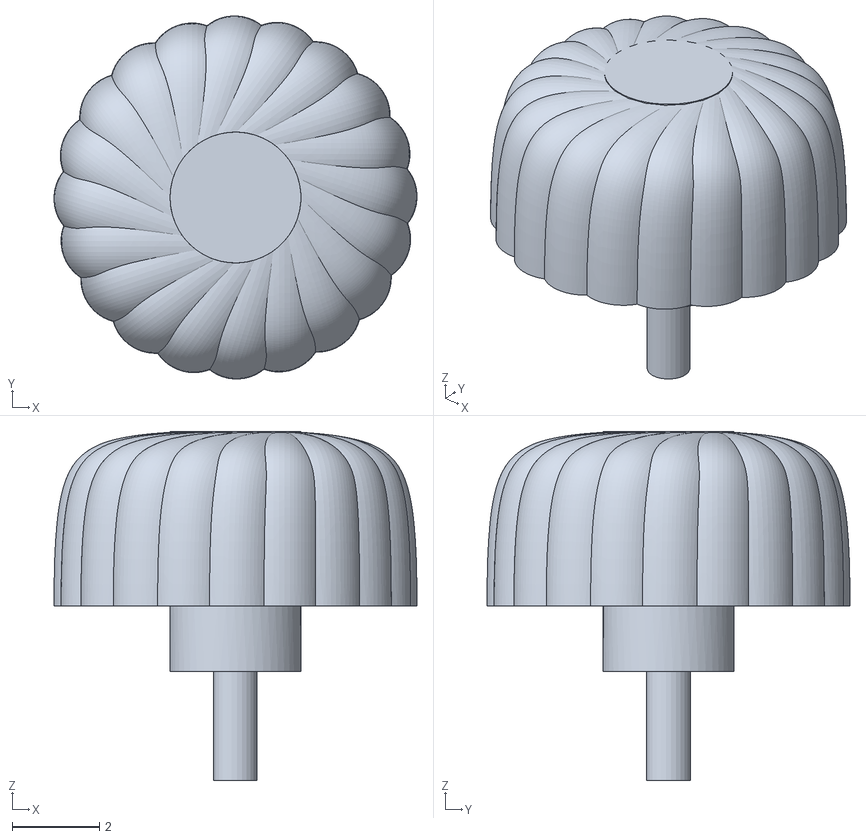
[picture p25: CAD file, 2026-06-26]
case/button/Bouton_STL/molette.stl
8.32 x 8.32 x 8.00

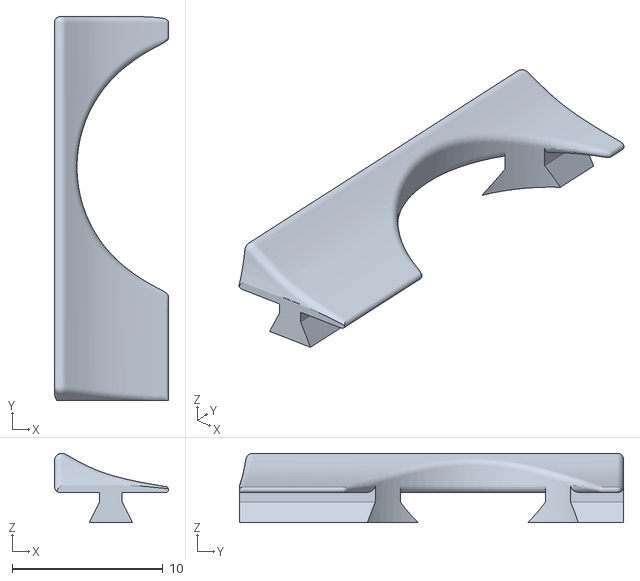
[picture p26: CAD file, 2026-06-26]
case/cardiometer/Cardiometre_STL/lowerRightPad.stl
7.58 x 25.5 x 4.61

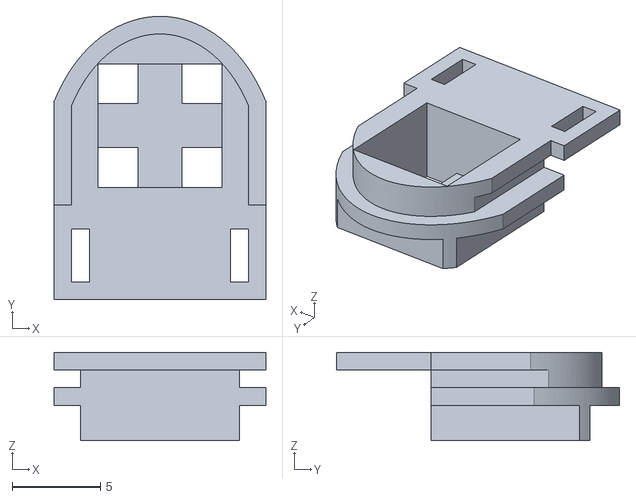
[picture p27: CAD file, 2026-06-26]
case/button/Bouton_STL/boitierDown.stl
12.0 x 16.0 x 5.00

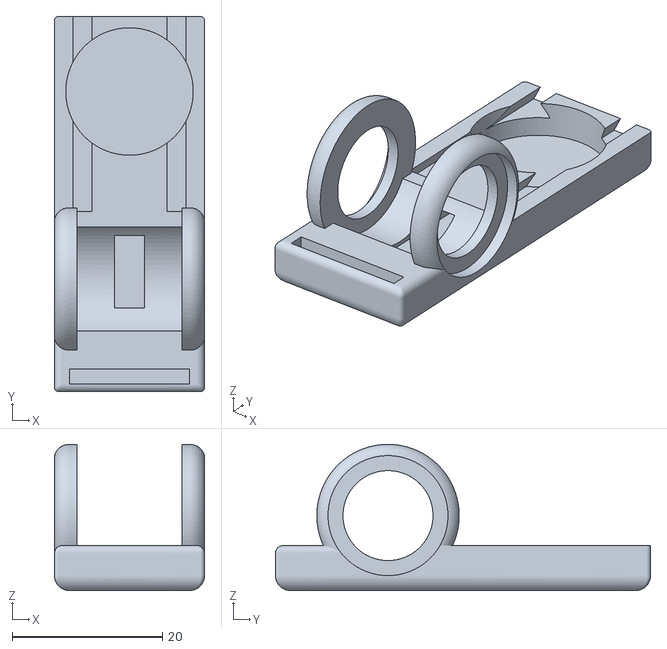
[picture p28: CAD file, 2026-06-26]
case/cardiometer/Cardiometre_STL/lowerjaw.stl
20.0 x 50.0 x 19.5

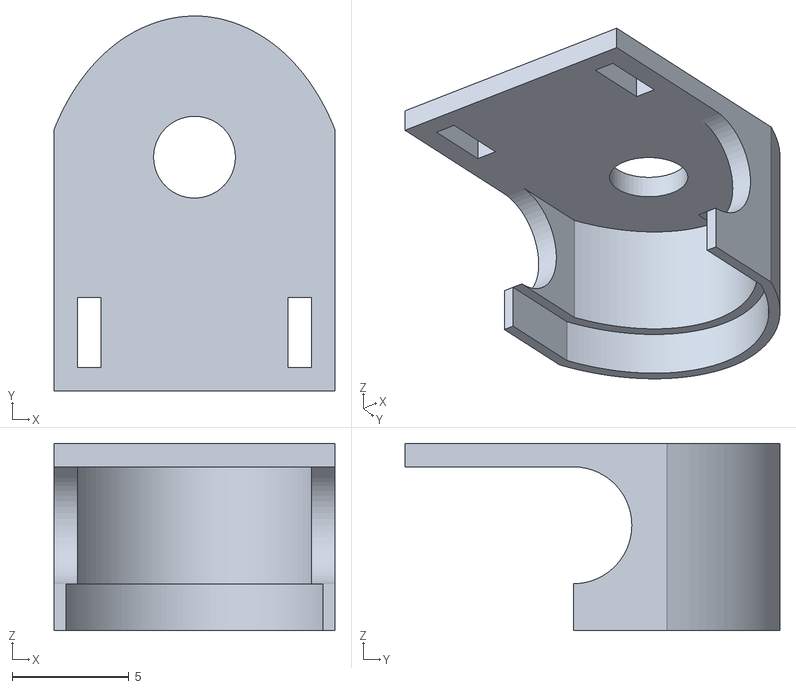
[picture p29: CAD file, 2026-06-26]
case/button/Bouton_STL/boitierUp.stl
12.0 x 16.0 x 8.00

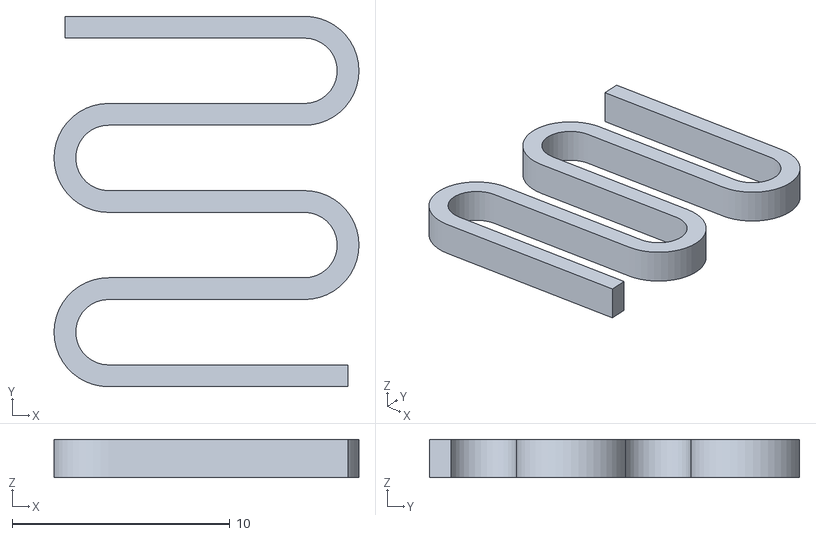
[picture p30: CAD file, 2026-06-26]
case/cardiometer/Cardiometre_STL/spring.stl
14.0 x 17.0 x 1.75

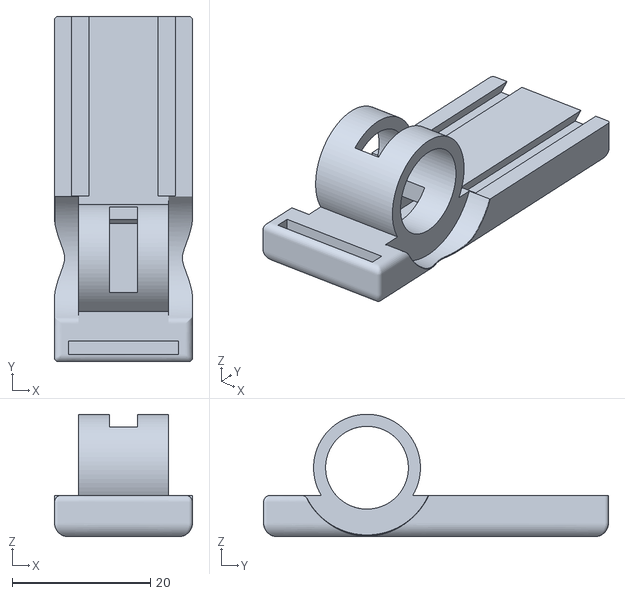
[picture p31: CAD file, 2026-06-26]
case/cardiometer/Cardiometre_STL/upperjaw.stl
20.0 x 50.0 x 17.7

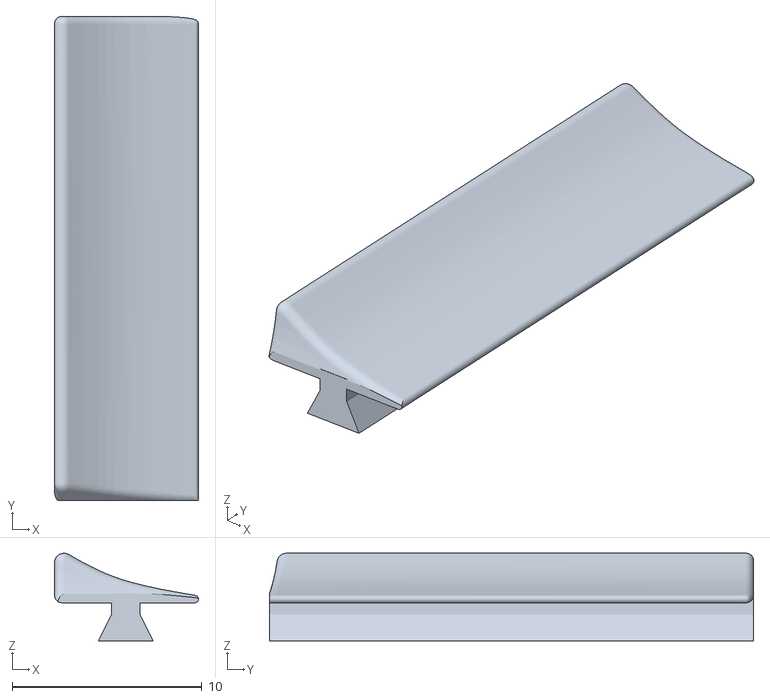
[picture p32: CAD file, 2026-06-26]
case/cardiometer/Cardiometre_STL/upperLeftPad.stl
7.58 x 25.5 x 4.61

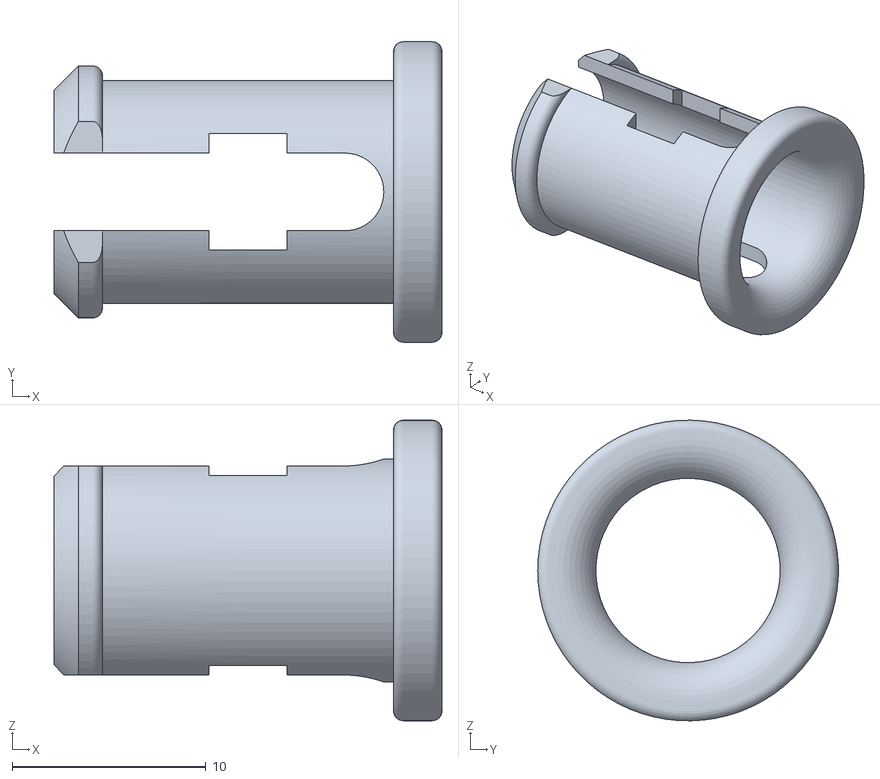
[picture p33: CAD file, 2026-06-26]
case/cardiometer/Cardiometre_STL/axis.stl
20.0 x 15.5 x 15.5

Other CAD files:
case/cardiometer/Cardiometre_STL/lowerLeftPad.stl
case/cardiometer/Cardiometre_STL/upperRightPad.stl

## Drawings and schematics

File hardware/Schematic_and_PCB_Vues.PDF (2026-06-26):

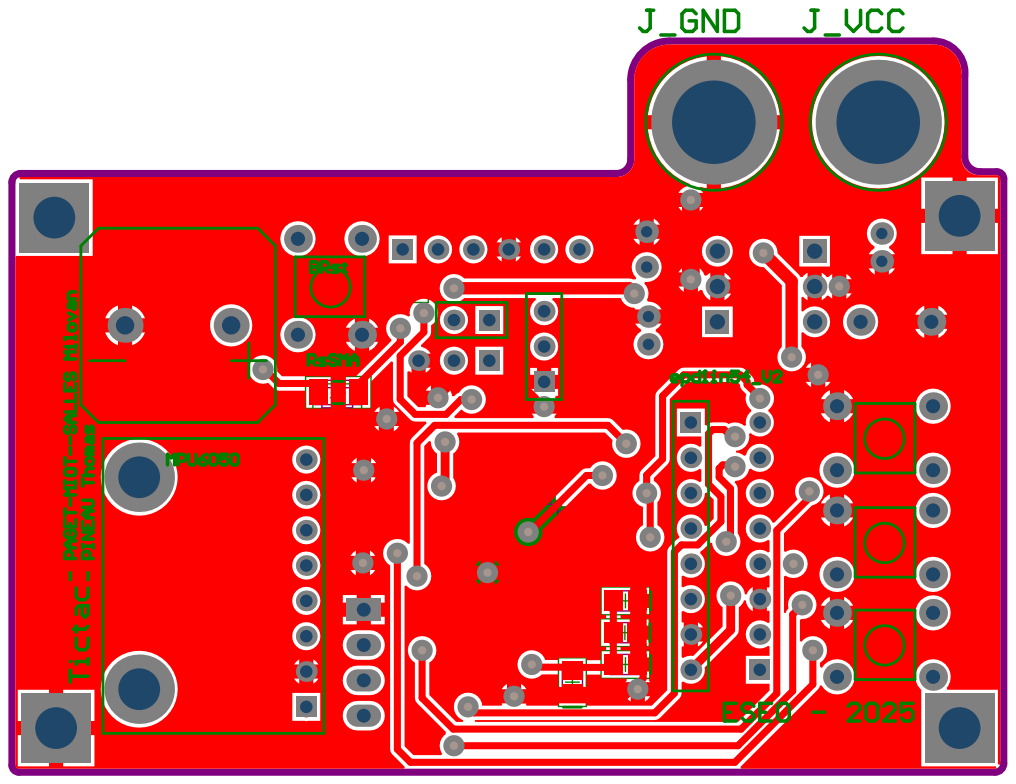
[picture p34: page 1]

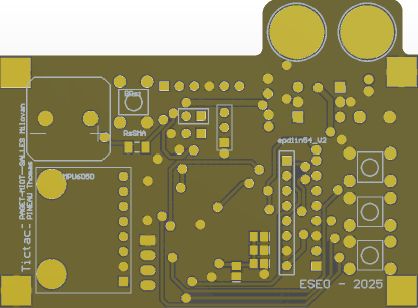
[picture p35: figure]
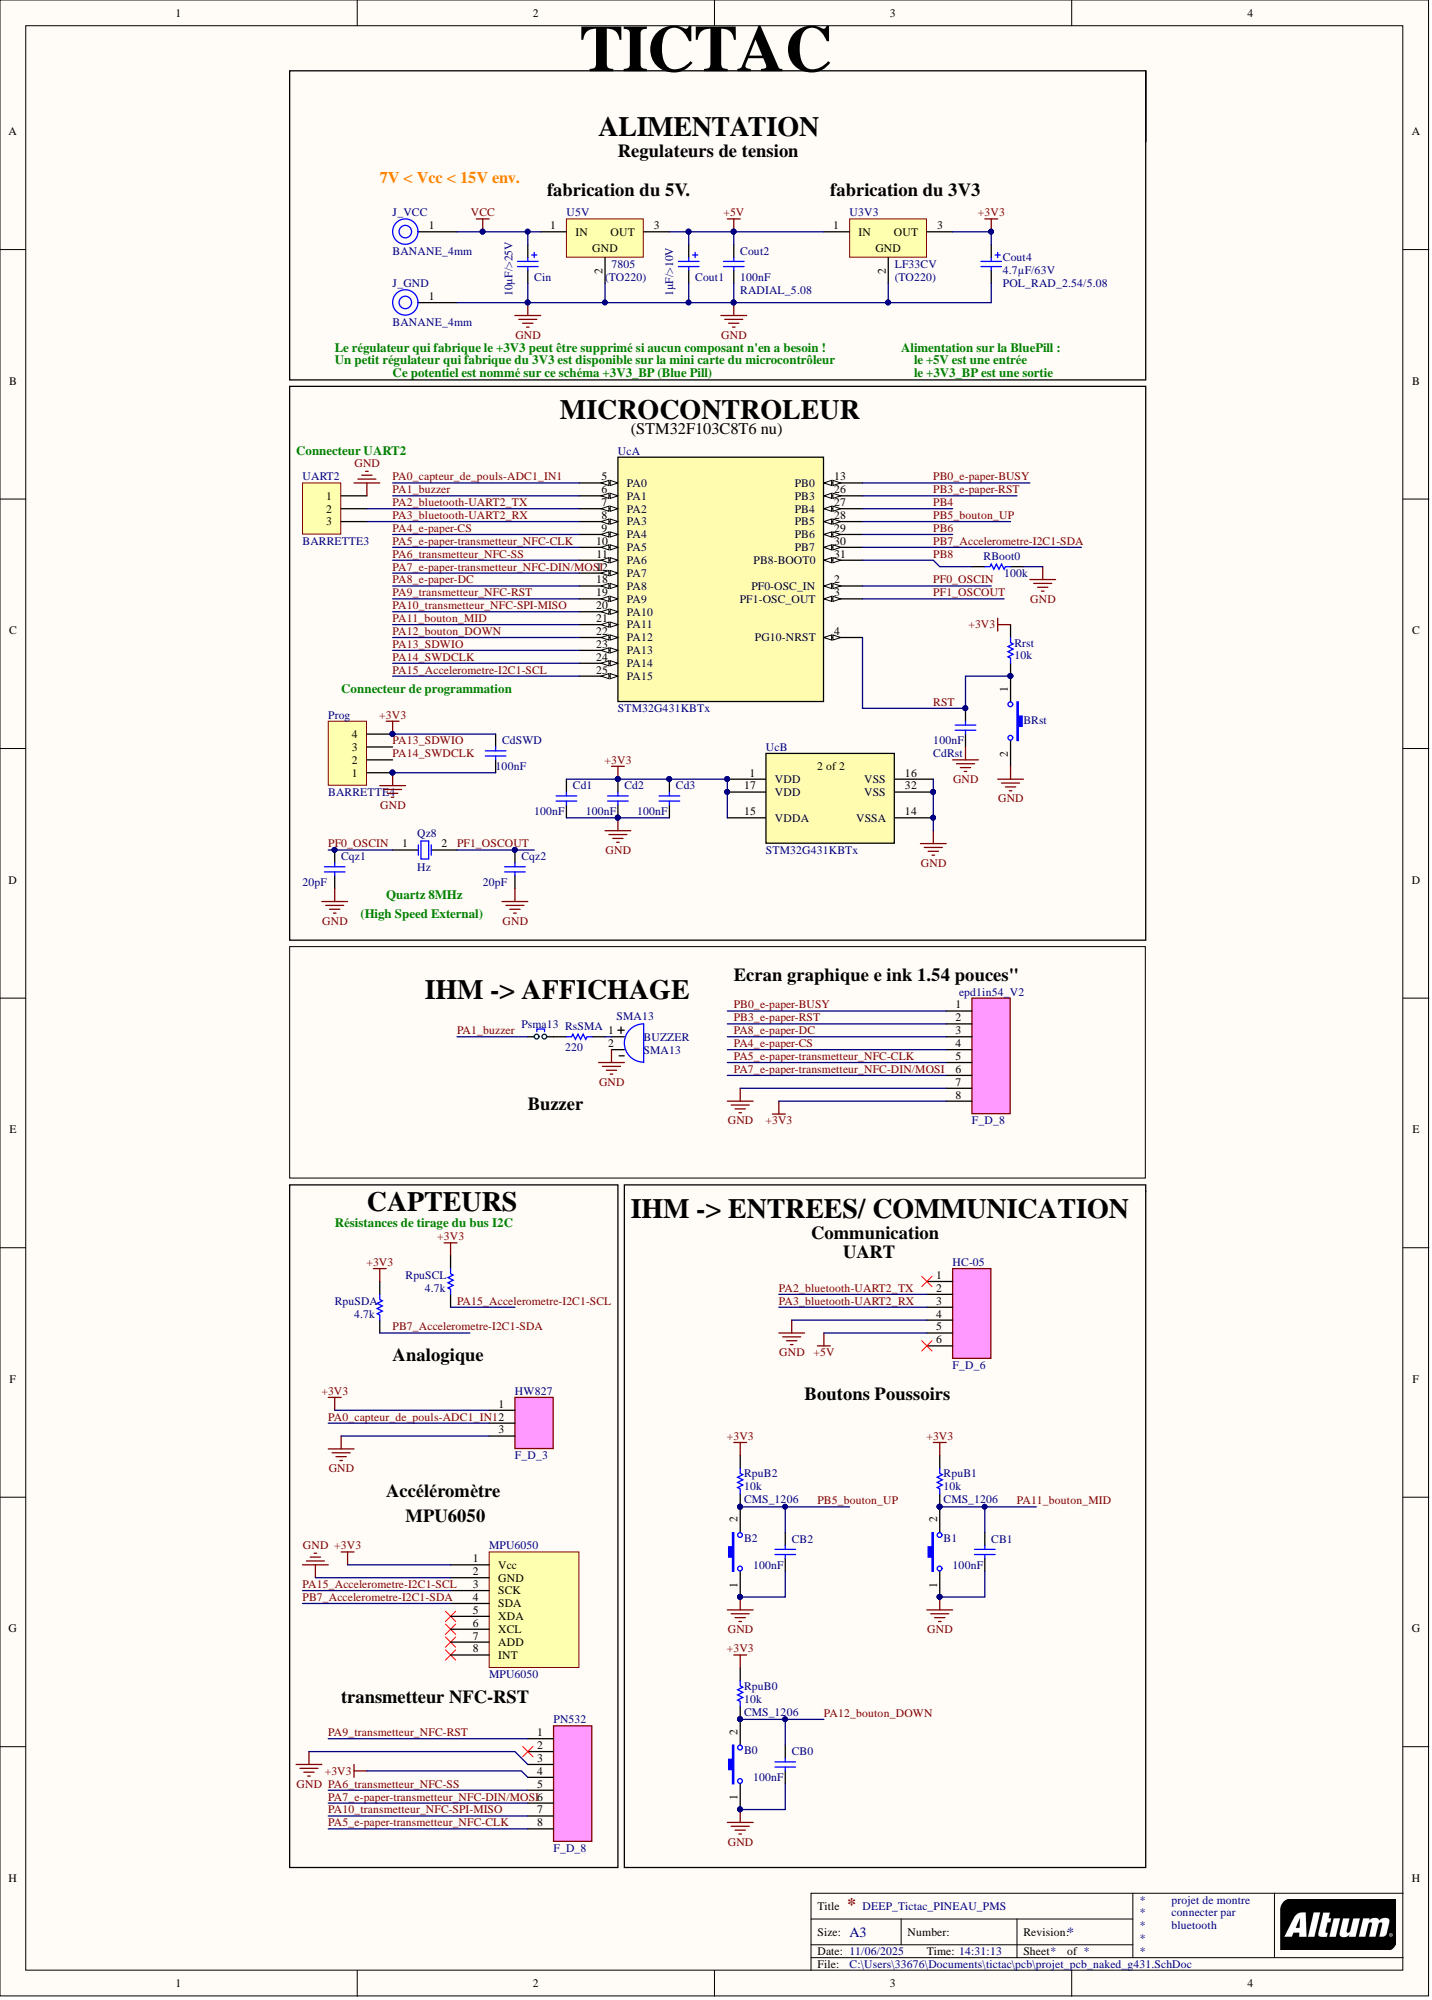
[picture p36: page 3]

Le régulateur qui fabrique le +3V3 peut être supprimé si aucun composant n'en a besoin !
Un petit régulateur qui fabrique du 3V3 est disponible sur la mini carte du microcontrôleur

Alimentation sur la BluePill :
le +5V est une entrée
le +3V3_BP est une sortie

Ce potentiel est nommé sur ce schéma +3V3_BP (Blue Pill)

Ecran graphique e ink 1.54 pouces"

Résistances de tirage du bus I2C

* DEEP_Tictac_PINEAU_PMS Title | * projet de montre * connecter par * bluetooth * *

A3 Size: | Number: | * Revision:
Date: 11/06/2025 Time: 14:31:13 | | Sheet * of *

C:\Users\33676\Documents\tictac\pcb\projet_pcb_naked_g431.SchDoc

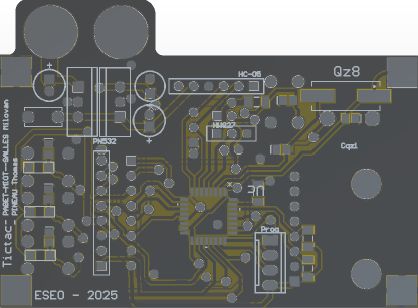
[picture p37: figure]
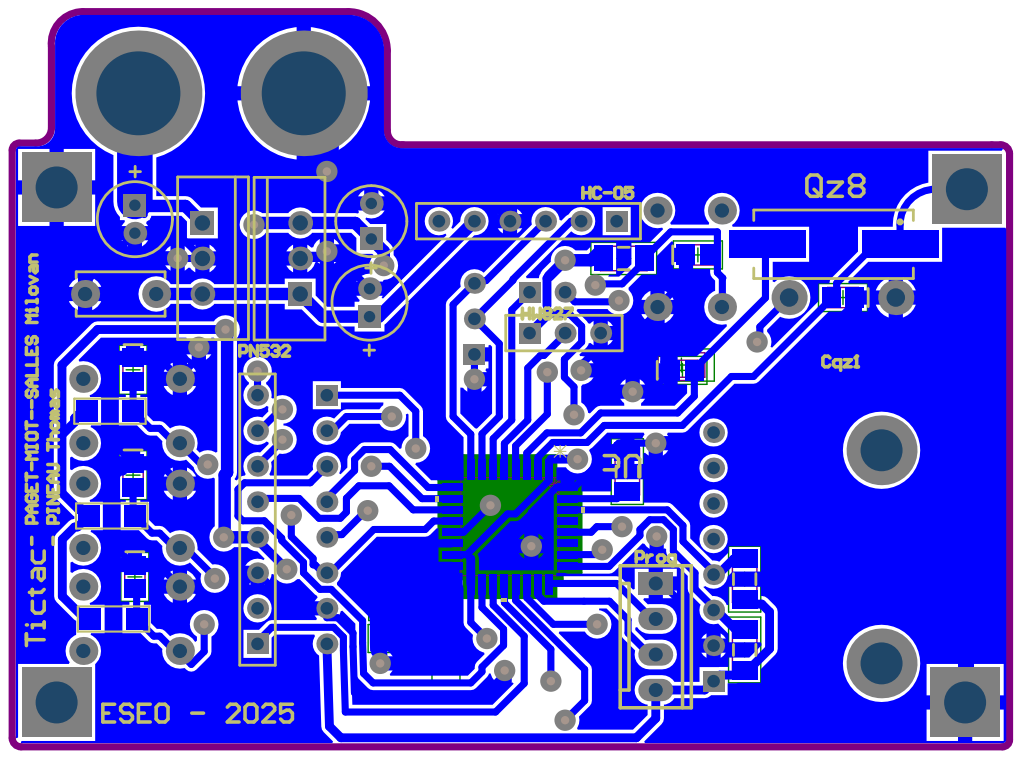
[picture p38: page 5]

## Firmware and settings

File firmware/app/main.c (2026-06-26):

/**
 * @file main.c
 * @author Thomas Pineau et Milovan Paget
 * @brief Fichier principal du projet de montre connectée avec écran e-paper, podomètre, capteur de pouls et communication Bluetooth
 * @date 12 mai 2025
 * @version 1.0
 *
 * Ce fichier contient la machine à états principale du système embarqué qui gère :
 * - L'affichage sur écran e-paper 1.54"
 * - Le comptage de pas via le capteur MPU6050
 * - La mesure du pouls avec le capteur HW827
 * - La communication Bluetooth HC-05
 * - L'interface utilisateur (boutons et encodeur rotatif)
 * - La gestion du temps via RTC
 *
 * @note Basé sur la documentation Waveshare : https://www.waveshare.com/wiki/1.54inch_e-Paper_Module_(B)_Manual#Working_With_STM32
 */

#include "config.h"

#include "stm32g4_sys.h"
#include "stm32g4_systick.h"
#include "stm32g4_gpio.h"
#include "stm32g4_uart.h"
#include "stm32g4_utils.h"
#include "stm32g4_adc.h"
#include "stm32g4_rtc.h"
#include "stm32g4_extit.h"
#include "stm32g4_timer.h"

#include <stdio.h>
#include <stdlib.h>
#include <stdbool.h>

// Bibliothèques Bluetooth (HC-05)
#include "./HC-05/stm32g4_hc05.h"
#include "./bluetooth/bluetooth_msg_process.h"

// Bibliothèque podomètre (MPU6050)
#include "./MPU6050/stm32g4_mpu6050.h"

// Bibliothèques écran e-paper
#include "./epaper/epaper.h"
#include "./epaper/epaper_displays.h"

// Bibliothèque RTC
#include "./rtc/rtc.h"

// Bibliothèques bouton central et encodeur rotatif
#include "./boutons/bouton_central.h"
#include "./boutons/encodeur_rotatif.h"

// Bibliothèque capteur de pouls (HW827)
#include "./heartbeat/heartbeat.h"

/**
 * @brief Énumération des états de la machine à états principale
 *
 * Cette énumération définit les différents états possibles du système :
 * - INIT : Phase d'initialisation de tous les périphériques
 * - IDLE : Mode veille avec affichage et actualisation de l'heure
 * - MENU : Navigation dans le menu principal
 * - DETECTION : Détection active des entrées utilisateur
 */
typedef enum {
    INIT,      // Initialisation des périphériques
    IDLE,      // Veille, affichage et actualisation de l'heure
    MENU,      // Menu principal
    DETECTION  // Détection active d'une entrée utilisateur
} State_t;

// Variables globales du système

/** @brief Structure de données du capteur MPU6050 */
MPU6050_t MPU6050_Data;

/** @brief Compteur de pas détectés par interruption */
volatile uint16_t pas_interupt = 0;

/** @brief Variable pour la mesure de l'encodeur rotatif */
volatile int lastEncoded = 0;

/** @brief État actuel de la machine à états */
State_t currentState = INIT;

/** @brief Indicateur du mode veille (true si en mode IDLE) */
bool inIdleMode = true;

/**
 * @brief Vérifie si un caractère a été reçu sur l'UART spécifié
 *
 * Cette fonction permet de détecter la réception d'un caractère sur une interface UART
 * sans bloquer l'exécution du programme.
 *
 * @param uart_id Identifiant de l'interface UART à vérifier
 * @return true si un caractère a été reçu, false sinon
 *
 * @pre L'interface UART doit être initialisée
 * @post Le caractère reçu est consommé s'il y en a un
 */
bool char_received(uart_id_t uart_id)
{
    if (BSP_UART_data_ready(uart_id))
    {
        BSP_UART_get_next_byte(uart_id);
        return true;
    }
    else
        return false;
}

/**
 * @brief Vérifie et met à jour l'affichage de l'heure si nécessaire
 *
 * Cette fonction compare l'heure actuelle avec la précédente et met à jour
 * l'affichage sur l'écran e-paper uniquement si l'heure ou la date a changé.
 * L'optimisation évite les rafraîchissements inutiles de l'écran.
 *
 * @pre Le système RTC doit être initialisé
 * @pre L'écran e-paper doit être initialisé
 * @pre Le système doit être en mode IDLE
 * @post L'affichage est mis à jour si l'heure/date a changé
 *
 * @note Cette fonction ne fait rien si le système n'est pas en mode IDLE
 */
void check_and_update_time_display() {
    static RTC_TimeTypeDef previousTime = {0};
    static RTC_DateTypeDef previousDate = {0};
    static bool first_run = true;

    if (!inIdleMode) return; // Ne pas mettre à jour si pas en mode IDLE

    RTC_TimeTypeDef currentTime;
    RTC_DateTypeDef currentDate;
    BSP_RTC_get_time_and_date(&currentTime, &currentDate);

    // Vérifier si l'heure ou la date ont changé
    if (first_run ||
        currentTime.Minutes != previousTime.Minutes ||
        currentTime.Hours != previousTime.Hours ||
        currentDate.Date != previousDate.Date) {

        // Mettre à jour l'affichage avec le nombre de pas
        EPD_Display_Idle(pas_interupt);

        // Sauvegarder l'heure et la date actuelles
        previousTime = currentTime;
        previousDate = currentDate;
        first_run = false;
    }
}

/**
 * @brief Machine à états principale du système
 *
 * Cette fonction implémente la logique principale du système.
 * Elle gère les transitions entre les différents états :
 * - Initialisation complète du système
 * - Mode veille avec affichage de l'heure
 * - Navigation dans les menus
 * - Détection des interactions utilisateur
 *
 * @pre Aucune précondition spécifique
 * @post L'état du système peut changer selon les conditions
 *
 * @note Cette fonction est appelée en boucle infinie dans main()
 */
void stateMachine() {
    static RTC_TimeTypeDef previousTime = {0};
    static RTC_DateTypeDef previousDate = {0};
    static bool first_run = true;

    switch (currentState) {
        case INIT:
            printf("Initialisation du système...\n");
            currentState = IDLE;

            // Initialisation de la couche d'abstraction matérielle STM32
            HAL_Init();

            // Configuration des broches GPIO
            BSP_GPIO_enable();

            // Initialisation UART2 pour le débogage (115200 bauds)
            BSP_UART_init(UART2_ID, 115200);
            BSP_SYS_set_std_usart(UART2_ID, UART2_ID, UART2_ID);

            // Initialisation UART1 pour la communication Bluetooth (115200 bauds)
            BSP_UART_init(UART1_ID, 115200);

            // Initialisation du convertisseur analogique-numérique
            BSP_ADC_init();

            // Initialisation de l'horloge temps réel
            RTC_Init();

            // Initialisation du capteur de mouvement MPU6050
            if (MPU6050_Init(&MPU6050_Data, GPIOA, GPIO_PIN_0, MPU6050_Device_0,
                             MPU6050_Accelerometer_8G, MPU6050_Gyroscope_2000s) != MPU6050_Result_Ok) {
                printf("Erreur lors de l'initialisation du MPU6050\n");
                while(1); // Blocage en cas d'erreur critique
            } else {
                printf("MPU6050 initialisé avec succès\n");
            }

            // Configuration du Timer 4 pour la détection de pas (période de 30 ms)
            BSP_TIMER_run_us(TIMER4_ID, 30000, true);

            // Configuration de la LED verte comme sortie
            BSP_GPIO_pin_config(LED_GREEN_GPIO, LED_GREEN_PIN, GPIO_MODE_OUTPUT_PP, GPIO_NOPULL, GPIO_SPEED_FREQ_HIGH, GPIO_NO_AF);

            // Configuration des boutons de l'encodeur rotatif avec interruptions
            BSP_GPIO_pin_config(BTN_GAUCHE_GPIO, BTN_GAUCHE_PIN, GPIO_MODE_IT_RISING_FALLING, GPIO_PULLUP, GPIO_SPEED_FREQ_LOW, GPIO_NO_AF);
            BSP_GPIO_pin_config(BTN_DROIT_GPIO, BTN_DROIT_PIN, GPIO_MODE_IT_RISING_FALLING, GPIO_PULLUP, GPIO_SPEED_FREQ_LOW, GPIO_NO_AF);

            // Configuration du bouton central comme entrée
            BSP_GPIO_pin_config(BTN_CENTRAL_GPIO, BTN_CENTRAL_PIN, GPIO_MODE_INPUT, GPIO_PULLDOWN, GPIO_SPEED_FREQ_LOW, GPIO_NO_AF);

            // Enregistrement des callbacks pour les interruptions de l'encodeur
            BSP_EXTIT_set_callback(encoder_callback, 12, true);  // Broche PA12
            BSP_EXTIT_set_callback(encoder_callback, 5, true);   // Broche PB5

            // Initialisation de l'état de l'encodeur
            lastEncoded = readEncoder();

            // Initialisation du capteur de pouls HW827
            HW827_Init();

            // Initialisation de l'interface SPI pour l'écran e-paper
            EPD_SPI_Init();

            // Initialisation du module écran
            DEV_Module_Init();

            // Initialisation de l'écran en mode partiel (plus rapide)
            EPD_Init();

            // Affichage de l'image de base
            EPD_DisplayBaseImage();

            inIdleMode = true;
            printf("Initialisation terminée\n");

            break;

        case IDLE:
            printf("Passage en mode IDLE\n");
            currentState = DETECTION;

            // Réinitialisation de l'écran et affichage de l'état de veille
            EPD_Display_Reset();
            EPD_Display_Idle(pas_interupt);

            // Activation du mode veille
            inIdleMode = true;

            // Mémorisation de l'heure actuelle pour éviter les rafraîchissements inutiles
            BSP_RTC_get_time_and_date(&previousTime, &previousDate);
            first_run = false;

            break;

        case MENU:
            // Désactivation du mode veille lors de l'entrée dans un menu
            inIdleMode = false;

            // Exécution de la machine à états de l'écran
            if (EPD_StateMachine() == 1) {
                currentState = IDLE;
                printf("Sortie de la machine à états EPD\n");
            }
            break;

        case DETECTION:
            // Traitement des données reçues via UART (Bluetooth)
            handle_uart_reception();

            // Vérification et mise à jour de l'affichage de l'heure
            check_and_update_time_display();

            // Affichage périodique du nombre de pas (pour le débogage)
            //printf("Pas détectés : %u\r\n", pas_interupt);

            // Détection de l'appui sur le bouton central
            if (read_central_button()) {
                BSP_UART_puts(UART2_ID, "BOUTON CENTRAL APPUYÉ\r\n", strlen("BOUTON CENTRAL APPUYÉ\r\n"));
                currentState = MENU;
                printf("Entrée dans le menu\n");
            }
            break;

        default:
            // État non défini, retour à l'initialisation
            printf("État inconnu, retour à l'initialisation\n");
            currentState = INIT;
            break;
    }
}

/**
 * @brief Fonction principale du programme
 *
 * Point d'entrée du programme qui lance la boucle infinie de la machine à états.
 * Le système fonctionne en mode événementiel, traitant continuellement les
 * entrées utilisateur et les données des capteurs.
 *
 * @return int Code de retour (jamais atteint dans ce cas)
 *
 * @pre Tous les périphériques matériels doivent être correctement connectés
 * @post Le système fonctionne en continu jusqu'à extinction
 *
 * @note Cette fonction ne se termine jamais en fonctionnement normal
 */
int main(void) {
    printf("Démarrage du système de Tictac\n");

    // Boucle principale infinie
    while (1) {
        stateMachine();
    }

    return 0; // Jamais atteint
}

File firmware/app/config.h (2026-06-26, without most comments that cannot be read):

/**
 *******************************************************************************
 * @file 	config.h
 * @author 	jjo
 * @date 	Mar 29, 2024
 * @brief	Fichier principal de configuration de votre projet sur carte Nucléo STM32G431KB.
 * 			Permet d'activer les différents modules logiciels à votre disposition.
 *******************************************************************************
 */

/* Define to prevent recursive inclusion -------------------------------------*/
#ifndef CONFIG_H_
#define CONFIG_H_


/* Includes ------------------------------------------------------------------*/
#include "stm32g4xx_hal.h"

/* Defines -------------------------------------------------------------------*/
#define LED_GREEN_PIN 		GPIO_PIN_8
#define LED_GREEN_GPIO 		GPIOB

#define BTN_GAUCHE_PIN	 		GPIO_PIN_12
#define BTN_GAUCHE_GPIO 		GPIOA

#define BTN_CENTRAL_PIN 		GPIO_PIN_11
#define BTN_CENTRAL_GPIO 		GPIOA

#define BTN_DROIT_PIN 		GPIO_PIN_5
#define BTN_DROIT_GPIO 		GPIOB

/*typedef enum {
    GAUCHE,
    CENTRAL,
	DROIT,
	RIEN
} Bouton_t;

extern Bouton_t boutonPresse;
extern Bouton_t detecter_bouton();*/

#define UART2_ON_PA3_PA2
#define UART1_ON_PA10_PA9

#define USE_BSP_TIMER		1
#define USE_BSP_EXTIT		1

#define USE_RTC				1

#define USE_ADC				1
	/* Configuration pour activer les entrées analogiques souhaitées */
	#define USE_IN1		1 //Broche correspondante: PA0
	#define USE_IN2		0 //Broche correspondante: PA1
	#define USE_IN3		0 //Broche correspondante: PA6
	#define USE_IN4		0 //Broche correspondante: PA7
	#define USE_IN10	0 //Broche correspondante: PF1 /!\ Broche indisponible sur g431 sauf si SB11 et pas SB10 (petits pads à souder sur la carte)
	#define USE_IN13	0 //Broche correspondante: PA5
	#define USE_IN17	0 //Broche correspondante: PA4

#define USE_DAC				0

/*------------------Afficheurs------------------*/
#define USE_ILI9341			0
#if USE_ILI9341
	#define USE_XPT2046			1
	#define USE_FONT7x10		1
	#define USE_FONT11x18		0
	#define USE_FONT16x26		0
#endif

#define USE_EPAPER			1
#define USE_WS2812			0 // Matrice de led

/*------------------Capteurs------------------*/
#define USE_MPU6050			1
#define USE_APDS9960		0
#define USE_BMP180			0
#define USE_BH1750FVI		0
#define USE_DHT11			0
#define USE_DS18B20			0
#define USE_YX6300			0 // Lecteur MP3
#define USE_MATRIX_KEYBOARD 0 // Clavier matriciel
#define USE_HCSR04			0
#define USE_GPS				0 // GPS
#define USE_LD19			0 // Lidar --> veuillez aussi activer USE_ILI9341, USE_XPT2046, USE_FONT7x10 et USE_FONT16x26 si vous voulez utiliser display_ld19.c
#define USE_NFC03A1			0 // Shield NFC
#define USE_VL53L0			0
#if USE_VL53L0
	#define VL53L0X_I2C			I2C1
	#define VL53_NB				1 // La version actuelle du driver ne peut traiter que 8 capteurs au maximum

	#define VL_0				GPIOA, GPIO_PIN_0 // Pin de reset
	//#define VL_1				GPIOD, GPIO_PIN_3
	//#define VL_2				GPIOE, GPIO_PIN_10
#endif

/*------------------Expanders------------------*/
#define USE_MCP23017		0 // GPIO expander qui communique en i2C
#define USE_MCP23S17		0 // GPIO expander qui communique en SPI
#define USE_SD_CARD			0

/*------------------Actionneurs------------------*/
#define USE_MOTOR_DC		0



#if USE_MLX90614 || USE_MPU6050	|| USE_APDS9960	 || USE_BH1750FVI || USE_BMP180 || USE_MCP23017 || USE_VL53L0 // Liste des modules utilisants le périphérique I2C
	#define USE_I2C				1
#else
	#ifndef USE_I2C
		#define USE_I2C				1
	#endif
#endif
#define I2C_TIMEOUT			5//ms

#if USE_ILI9341 || USE_SD_CARD || USE_MCP23S17 || USE_EPAPER
	#define USE_SPI				1
#else
	#ifndef USE_SPI
		#define USE_SPI				1
	#endif
#endif

#define USE_TESTBOARD				0


#endif /* CONFIG_H_ */

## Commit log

2025-03-30 epaper - Adaptation des libraries epd1in54_V2
    https://files.waveshare.com/upload/7/71/E-Paper_code.zip
2025-03-30 epaper - Ajout de source
    https://www.waveshare.com/wiki/1.54inch_e-Paper_Module_(B)_Manual#Working_With_STM32
2025-04-02 PCB - Dossier du PCB créé
2025-04-02 epaper - Déplacement de la démo de l'écran dans epaper.c
    Création de epaper.c & epaper.h
2025-04-02 Heartbeat - Création des fichiers et activation ADC
2025-04-09 Autres - Ajout des fichiers epaper pour Arduino et STM32
2026-06-26 Clean reupload
    [DEEP.PcbLib, DEEP.SchLib, affichage.PcbLib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]
2026-06-27 Update and rename cao.md to cad.md
2026-06-27 Add cad screenshots
2026-06-27 Add cad screenshot
